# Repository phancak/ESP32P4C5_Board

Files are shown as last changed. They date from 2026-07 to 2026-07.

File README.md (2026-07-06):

# Modular ESP32 Heterogeneous Computing Platform (ESP32-P4 + ESP32-C5)

<div align="center">
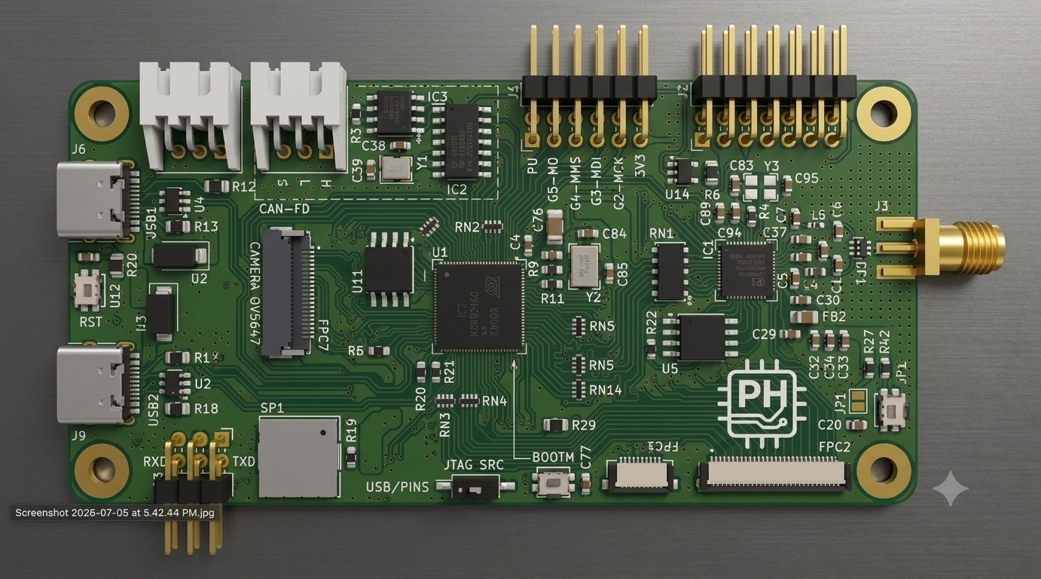
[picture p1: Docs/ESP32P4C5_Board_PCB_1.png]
ESP32P4C5 PCB 3D Render
  
  <br>
  <em>4-layer PCB diagram.</em>
</div>





## 📑 Quick Access
* [**📂 View Project Schematics (PDF)**](./Schematics/ESP32P4C5_Board.pdf)
* [**📂 View PCB Layout (PDF)**](./PCB_Layout/ESP32P4C5_Board.pdf)

## 📌 Project Overview

A production-grade, high-performance development platform engineered to serve as a modular, reusable core for edge computing, high-bandwidth multimedia processing, and synchronized wireless gateways. 

This repository showcases an advanced asynchronous, dual-MCU topology that isolates intensive computational and real-time interface operations from wireless network stack overhead. By decoupling heavy application logic from communication tasks via a high-speed parallel bus interconnect, the architecture guarantees deterministic processing latency and maximum deployment flexibility across diverse industrial and machine vision domains.

---

## 🏗 System Architecture & Design Philosophy

The system architecture purposefully segregates application compute from wireless networking to maximize throughput and guarantee real-time predictability.

<div align="center">
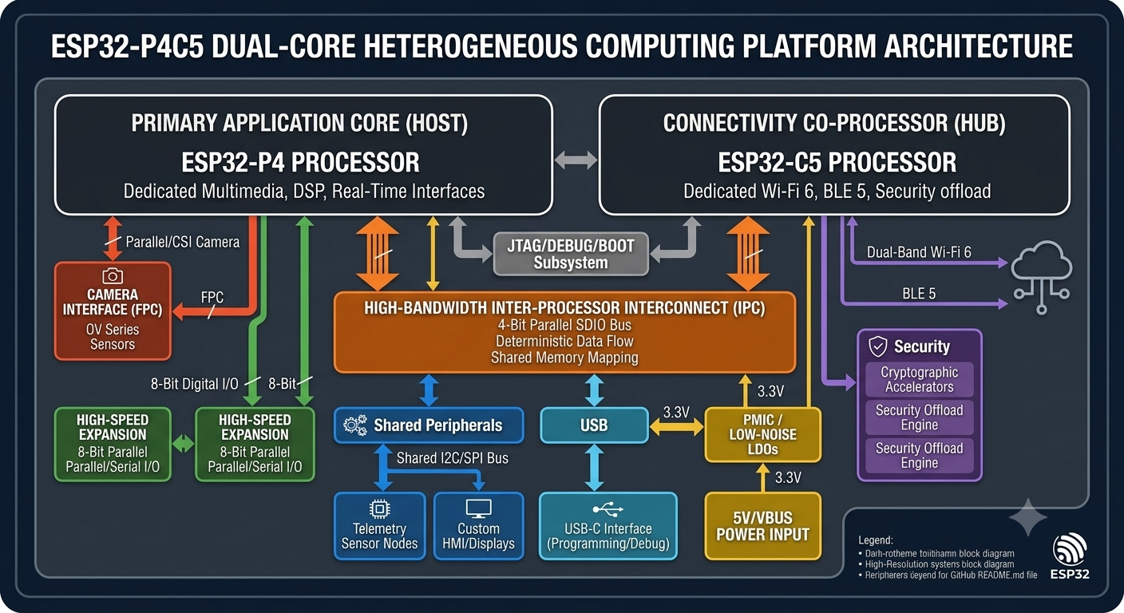
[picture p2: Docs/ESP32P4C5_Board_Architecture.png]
ESP32P4C5 System architecture diagram
  
  <br>
  <em>System architecture diagram.</em>
</div>

### 1. Primary Workstation Core: Espressif ESP32-P4
The **ESP32-P4** acts as the primary host, running application firmwares, digital signal processing (DSP), and complex interface state-machines. It interfaces with high-bandwidth peripherals without experiencing interrupt starvation caused by networking radio activity.
*   **Camera FPC Interface:** A dedicated 0.5mm pitch FPC interface supporting parallel/MIPI CSI camera modules. Designed for minimal trace-length skew to support synchronous high-frame-rate image acquisition and local edge execution.
*   **8-Bit Parallel Subsystem:** Exposes a high-speed, parallel digital bus mapped directly onto low-latency GPIO matrices. Engineered to interface directly with legacy parallel hardware, hardware accelerators, rapid external analog-to-digital converters (ADCs), or high-refresh TFT displays.

### 2. Network Co-Processor Subsystem: Espressif ESP32-C5
The **ESP32-C5** operates as a standalone network engine, handling the entirety of the link layer, cryptographic handshakes, and transport layer protocol stacks.
*   **Dual-Band Wi-Fi 6:** Utilizes native 2.4 GHz and 5 GHz radios, providing network resilience against RF congestion, significantly improving communication reliability in dense industrial environments.
*   **Bluetooth 5 (LE):** Managed independently for local out-of-band provisioning, decentralized mesh topologies, and real-time proximity sensing.

### 3. Inter-Processor Communication (IPC): 4-Bit SDIO Bus
Processor synchronization is achieved over a hardware-managed **4-bit SDIO parallel interface**. Unlike highly bottlenecked SPI or serial UART abstractions, this interconnect introduces wide data paths capable of handling high-rate simultaneous dual-band Wi-Fi data routing concurrently with video capture or high-speed I/O manipulation.

---

## 🔌 Hardware Interface Mapping

To fulfill its requirements as a universally integrable module, the layout strictly organizes peripheral pin assignments to mitigate trace crossover and manage signal integrity across high-speed signal groups.

| Peripheral Subsystem | Physical Interface / Interconnect | Target Engineering Application |
| :--- | :--- | :--- |
| **Edge Vision** | 0.5mm Pitch Parallel FPC | CMOS Image Sensors, Edge AI Machine Vision, Asset Monitoring |
| **Parallel Bus** | Low-Impedance GPIO Headers | Legacy Bus Bridging, High-Speed External Converters, Parallel LCDs |
| **Synchronous Serial**| Hardware SPI Bus Headers | High-Frequency IMUs, External Flash Memory, Low-Level Controllers |
| **Asynchronous Serial**| Dedicated Hardware UART | isolated Console Debugging, GNSS Modems, Cellular Modems |
| **Control Bus** | Fast-Mode Plus (Fm+) I2C | Local Telemetry Sensors, Cryptographic Co-Processors, EEPROMs, HMIs |
| **System I/O & Power** | Dual Independent USB-C | Native USB 2.0 Subsystems, Dedicated Programming/Debugging Bridges |

---

## 🚀 Target Production Domain Implementations

*   **Distributed Edge Machine Vision:** Acquires high-fidelity pixel matrices via the FPC interface, executes localized machine learning inference directly on the application core, and marshals real-time vectors safely out through dual-band Wi-Fi 6.
*   **Industrial Automation & Edge HMI:** Interconnects cleanly with external motor controllers, fieldbuses, or dense sensor pods via the 8-bit parallel, SPI, or I2C busses while handling real-time visualization on local touch displays.
*   **Secure IoT Sensor Hubs:** Operates as a security gateway, pulling data from localized wireless sensor clusters via BLE 5 and uploading encrypted data streams to enterprise cloud nodes across secure 5 GHz channels.

---

## 🛠 System Compilation & Initialization Workflow

### Technical Prerequisites
*   **Espressif ESP-IDF SDK v5.3+** (or later stable branches containing target support for the ESP32-P4 architecture).
*   Standard dual-channel USB-to-UART bridging hardware or explicit configuration via internal USB routing layers.

### Compiling and Deployment
To compile and flash the primary application workspace onto the main ESP32-P4 target engine:

```bash
# Navigate to the core processor application repository
cd firmware/main_p4

# Set compilation targets explicitly to the ESP32-P4 hardware register maps
idf.py set-target esp32p4

# Execute target compilation and code optimization pass
idf.py build

# Flash binary payloads onto the hardware module and open serial communication lines
idf.py -p [YOUR_TARGET_PORT] flash monitor
```

## 📝 License & Open Source Compliance
This architecture and firmware codebase are released under the terms of the open-source MIT License. For complete text and details regarding reuse rights, consult the accompanying LICENSE file.

## 🎓 About the Author
I am a recent **Electrical Engineering graduate from the University of British Columbia (UBC)**. This project represents my ability to transition theoretical academic knowledge into a complex, manufacturable high-speed digital system.

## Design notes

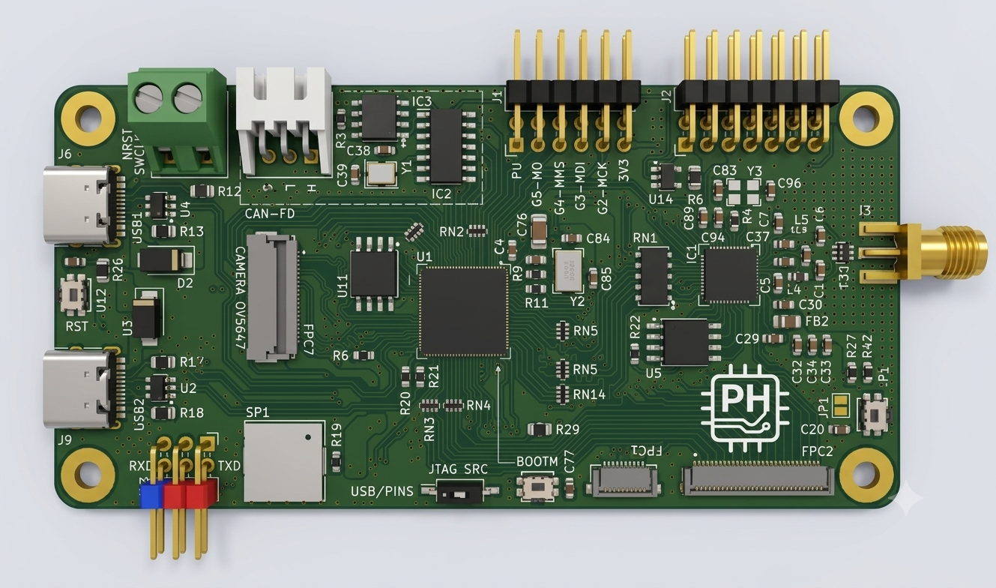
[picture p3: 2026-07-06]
Docs/ESP32P4C5_Board_PCB.png

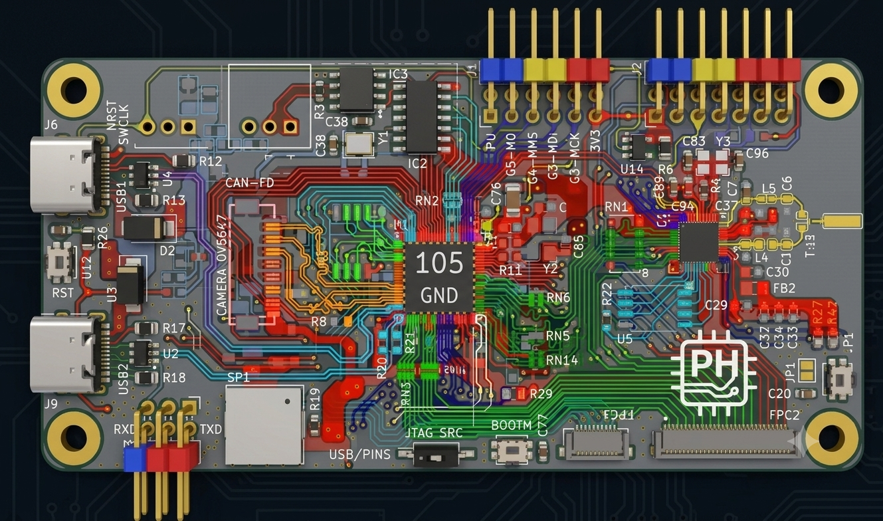
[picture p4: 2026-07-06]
Docs/ESP32P4C5_Board_PCB_Layout.png

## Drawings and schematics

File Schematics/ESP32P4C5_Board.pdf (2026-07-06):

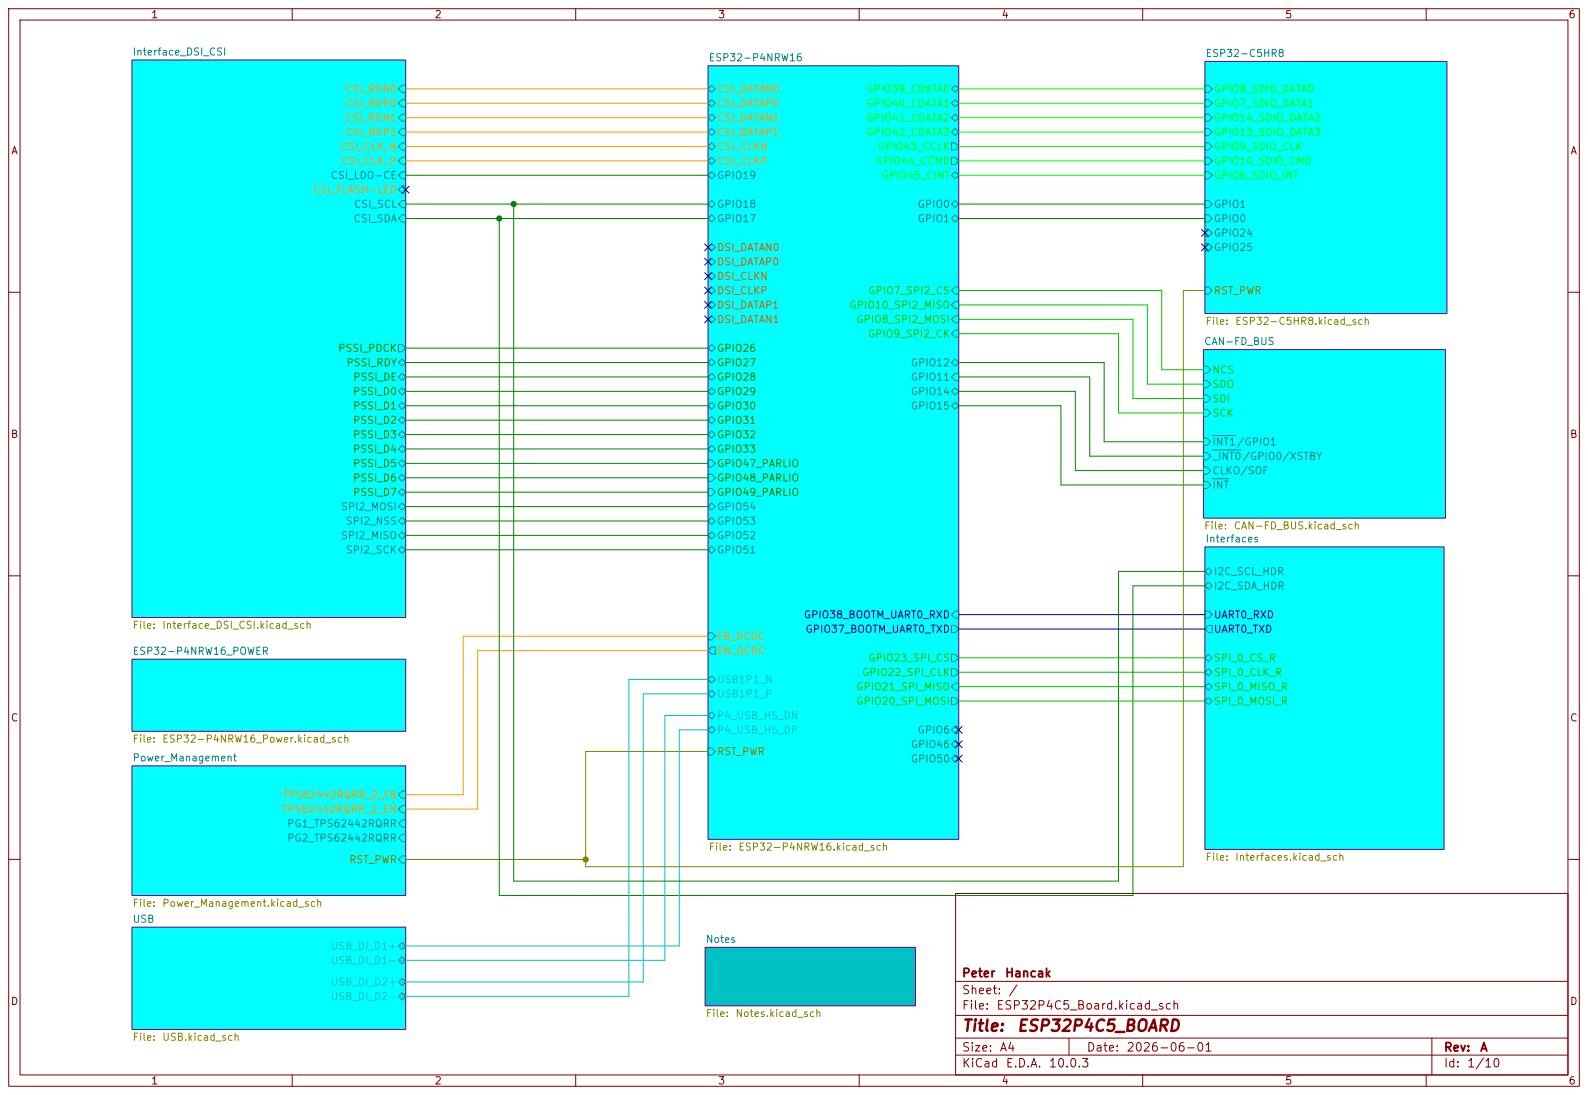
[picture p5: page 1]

CLKO/SOF SCK NCS

File: CAN-FD_BUS.kicad_sch Notes File: Notes.kicad_sch

Size: A4 | Rev: A
KiCad E.D.A. 10.0.3 | Id: 1/10

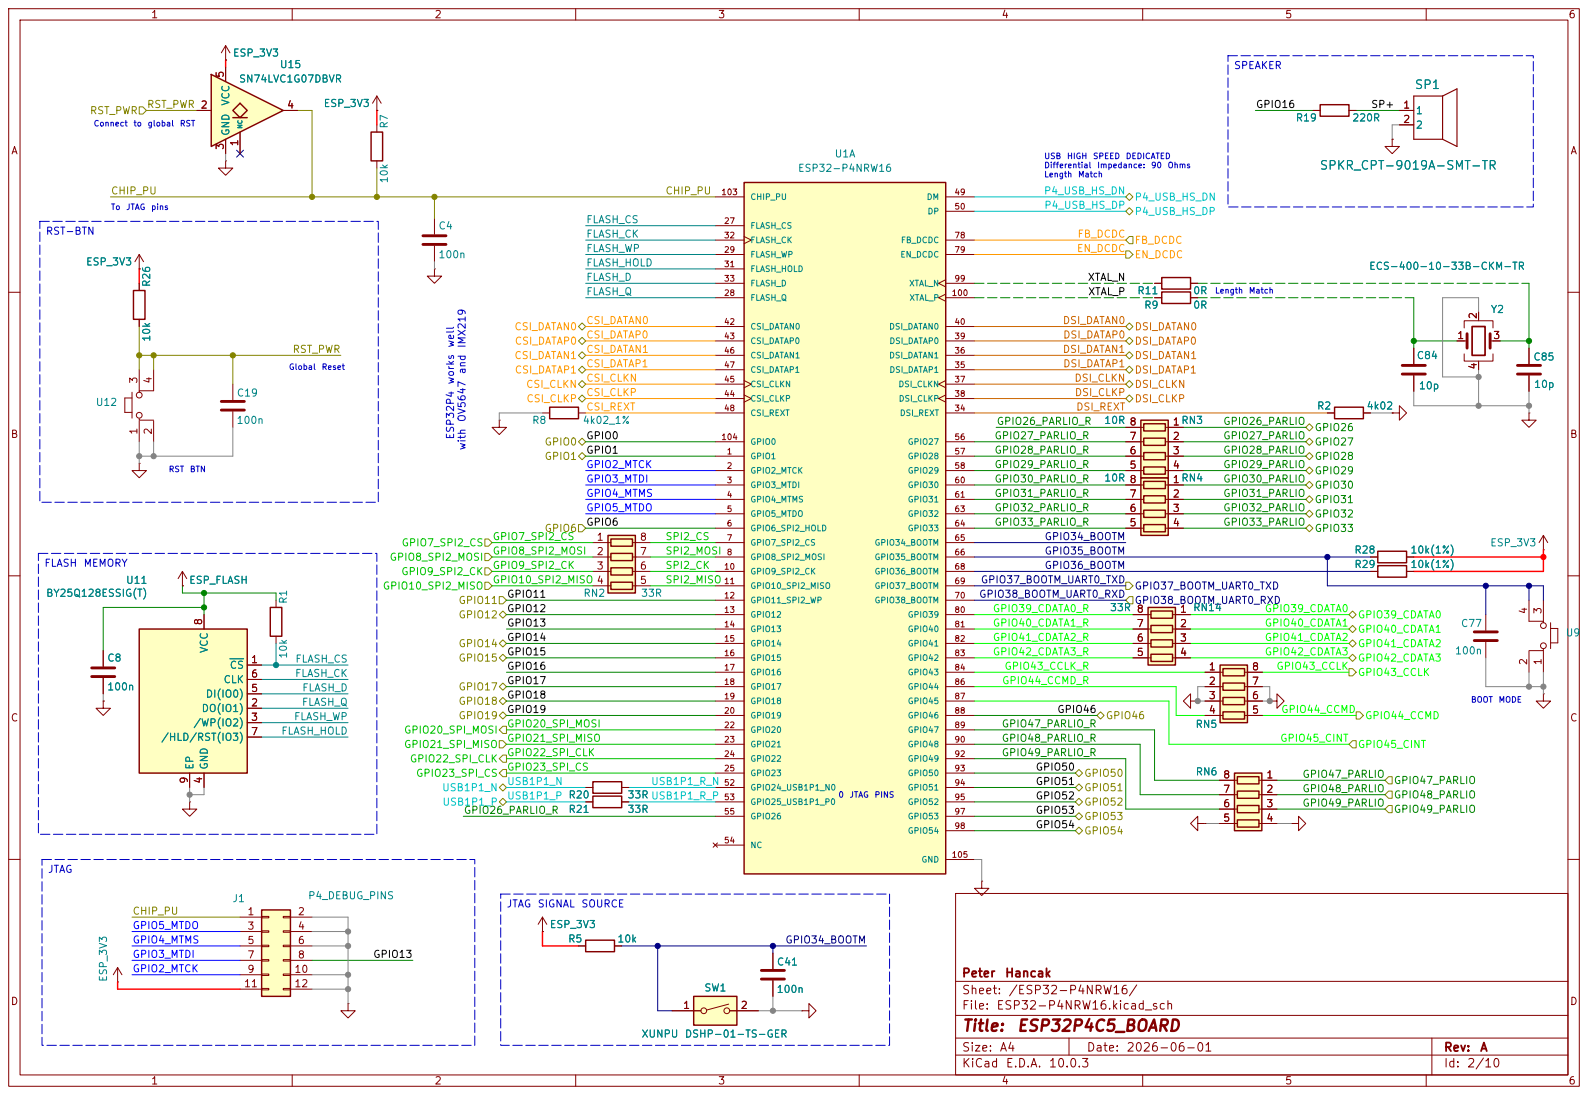
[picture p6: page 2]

Length Match RST BTN

4 DI(IO0) 5 CLK 6 /HLD/RST(IO3) 7 VCC

GPIO40_CDATA1_R 7 7 | 2 2 GPIO40_CDATA1
GPIO41_CDATA2_R 6 6 | GPIO41_CDATA2 3 3
GPIO42_CDATA3_R 5 5 | 4 4 GPIO42_CDATA3

XUNPU DSHP-01-TS-GER

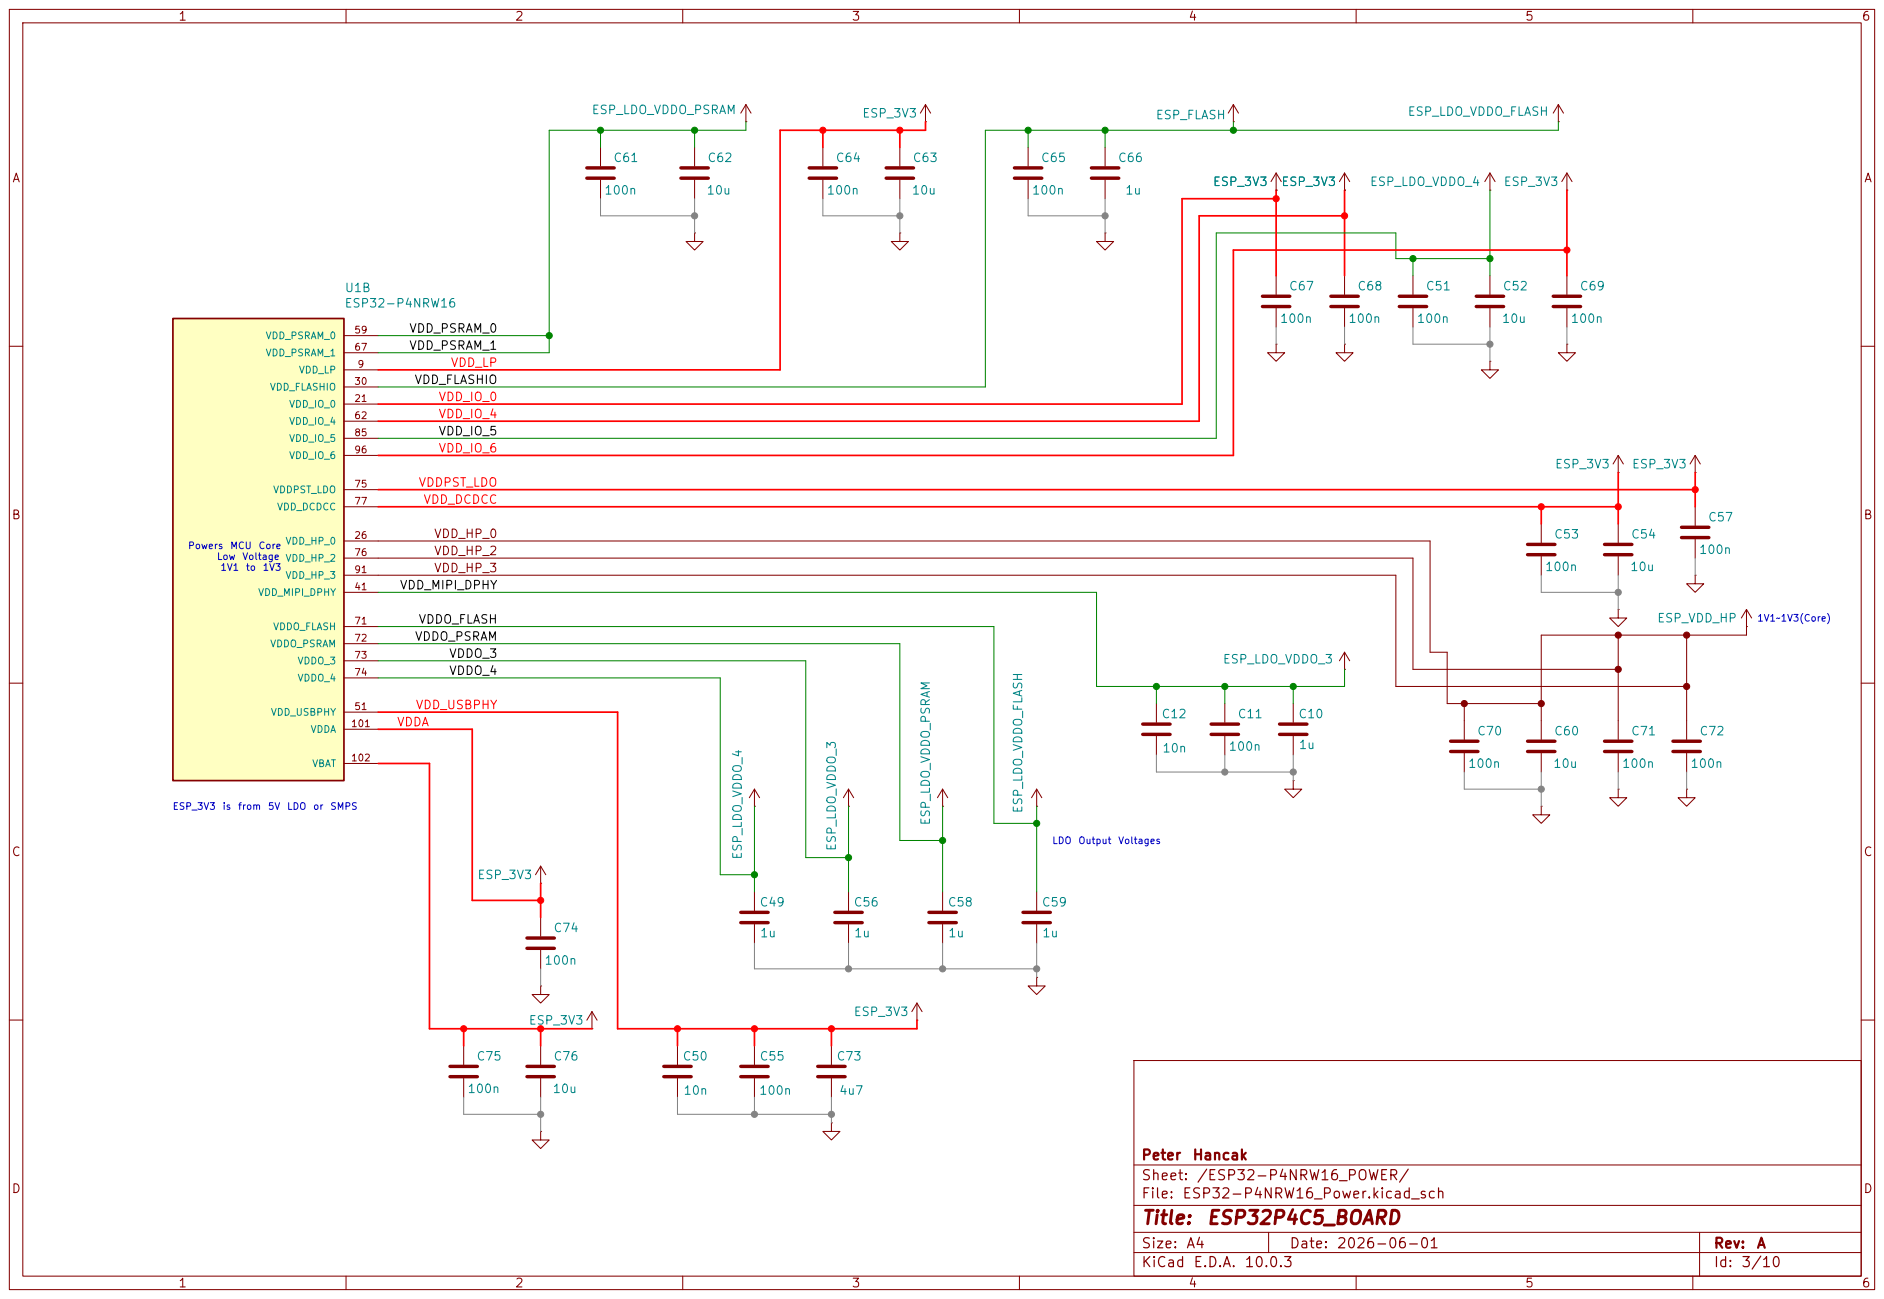
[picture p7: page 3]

VDD_DCDCC

VDD_HP_0

ESP_3V3 is from 5V LDO or SMPS

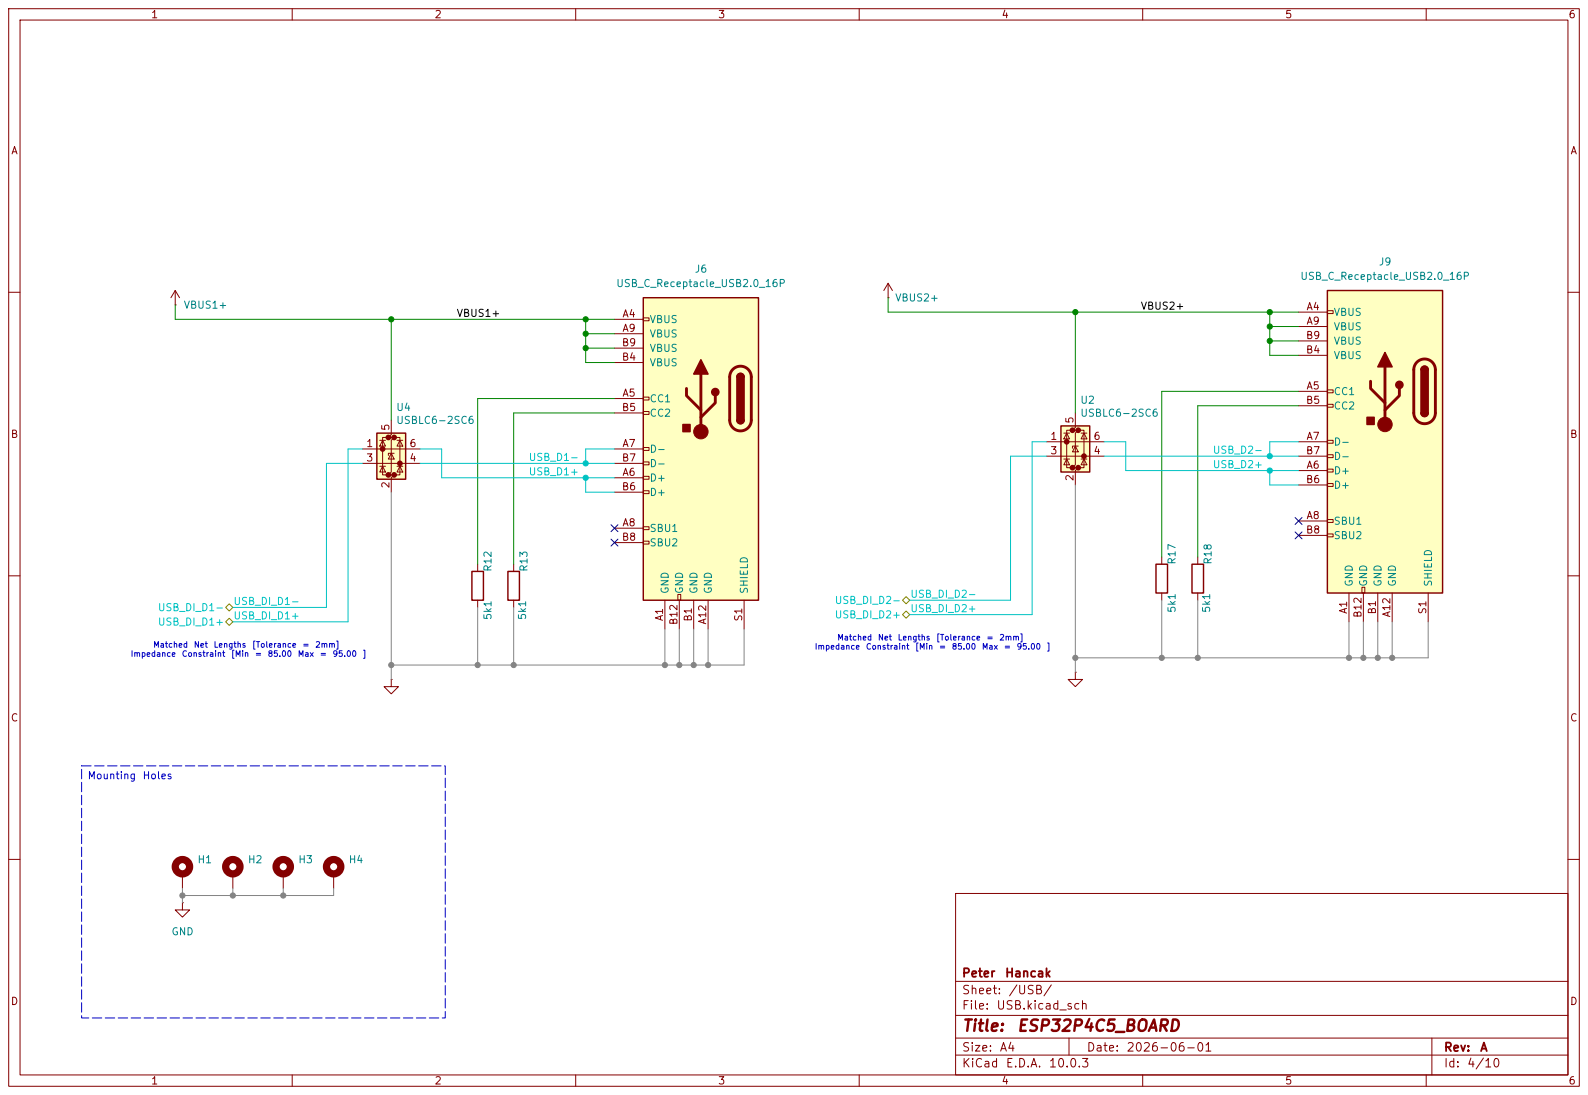
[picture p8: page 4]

VBUS B4 CC2 B5 D+ B6 D- B7

USB_D1+

USB_D2+

Mounting Holes Matched Net Lengths [Tolerance = 2mm]

Impedance Constraint [Min = 85.00 Max = 95.00 ]

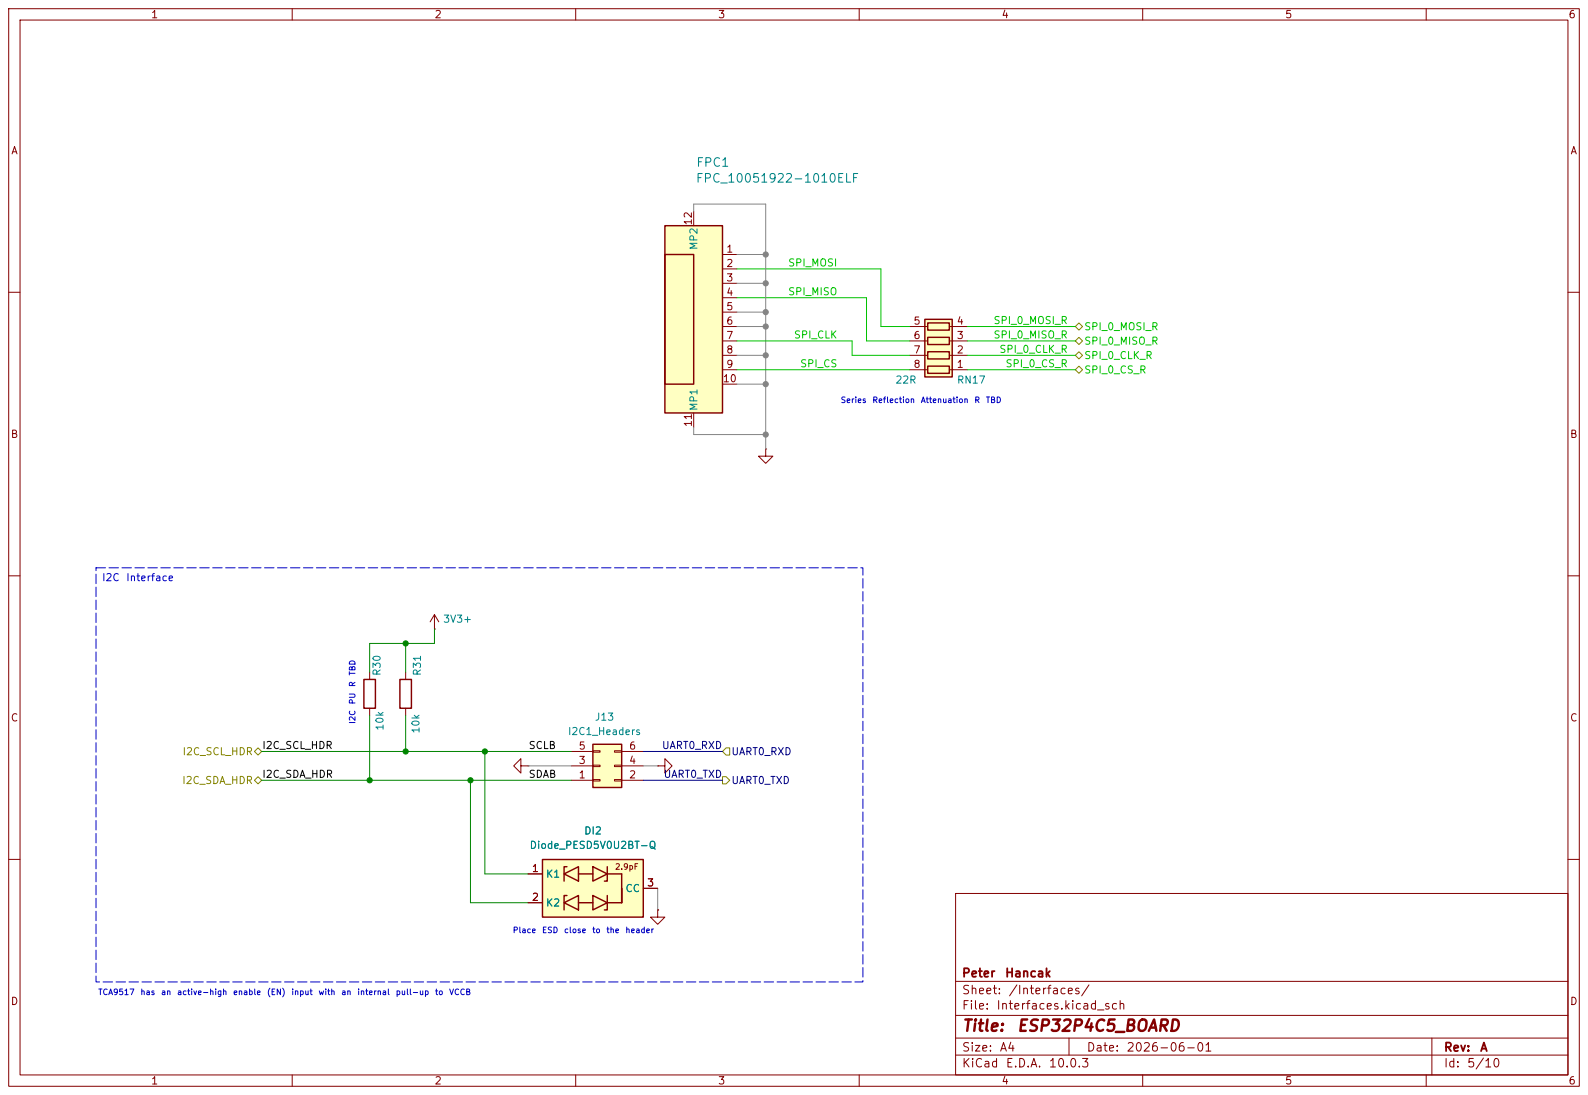
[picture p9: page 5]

8 | SPI_CS | 7

Series Reflection Attenuation R TBD

Place ESD close to the header I2C PU R TBD

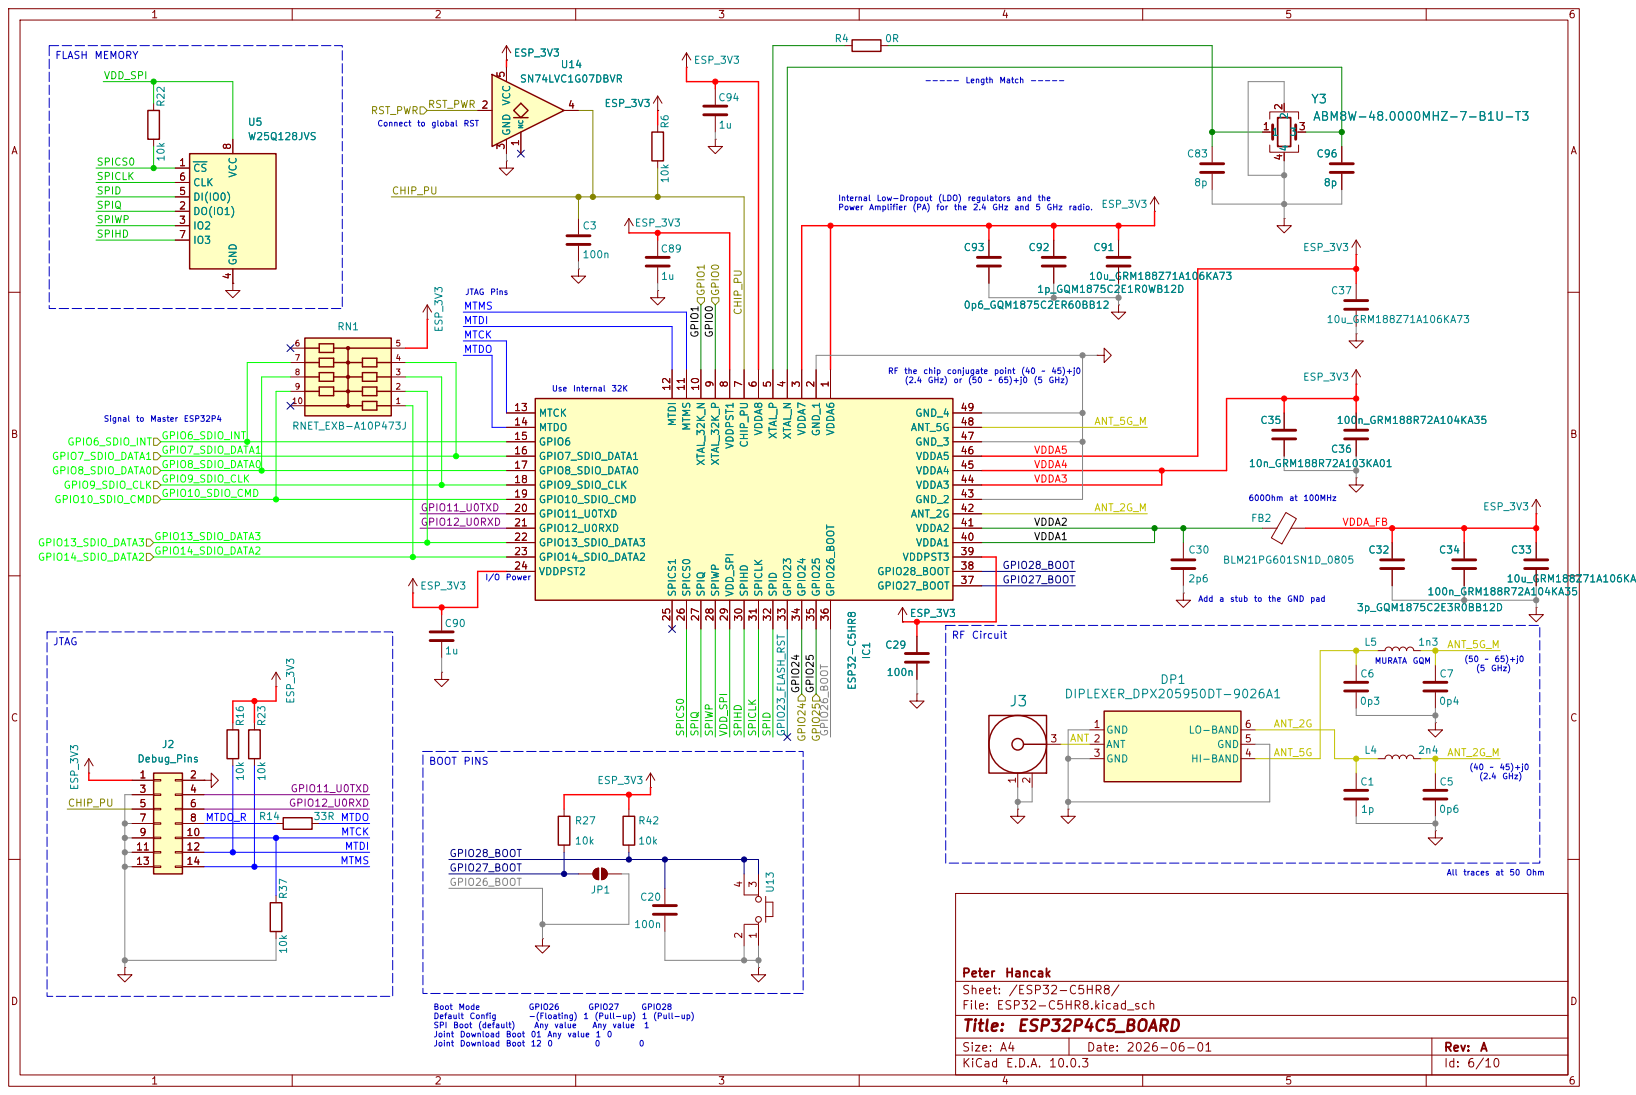
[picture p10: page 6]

RF the chip conjugate point (40 ~ 45)+j0
(2.4 GHz) or (50 ~ 65)+j0 (5 GHz)

9 XTAL_32K_N 10 MTMS 11 MTDI 12 MTCK 13 MTDO 14 GPIO6 15 GPIO7_SDIO_DATA1 16 GPIO8_SDIO_DATA0 17 GPIO9_SDIO_CLK 18 GPIO10_SDIO_CMD 19 GPIO11_U0TXD 20 GPIO12_U0RXD 21 GPIO13_SDIO_DATA3 22 GPIO14_SDIO_DATA2 23

Joint Download Boot 01 Any value 1 0

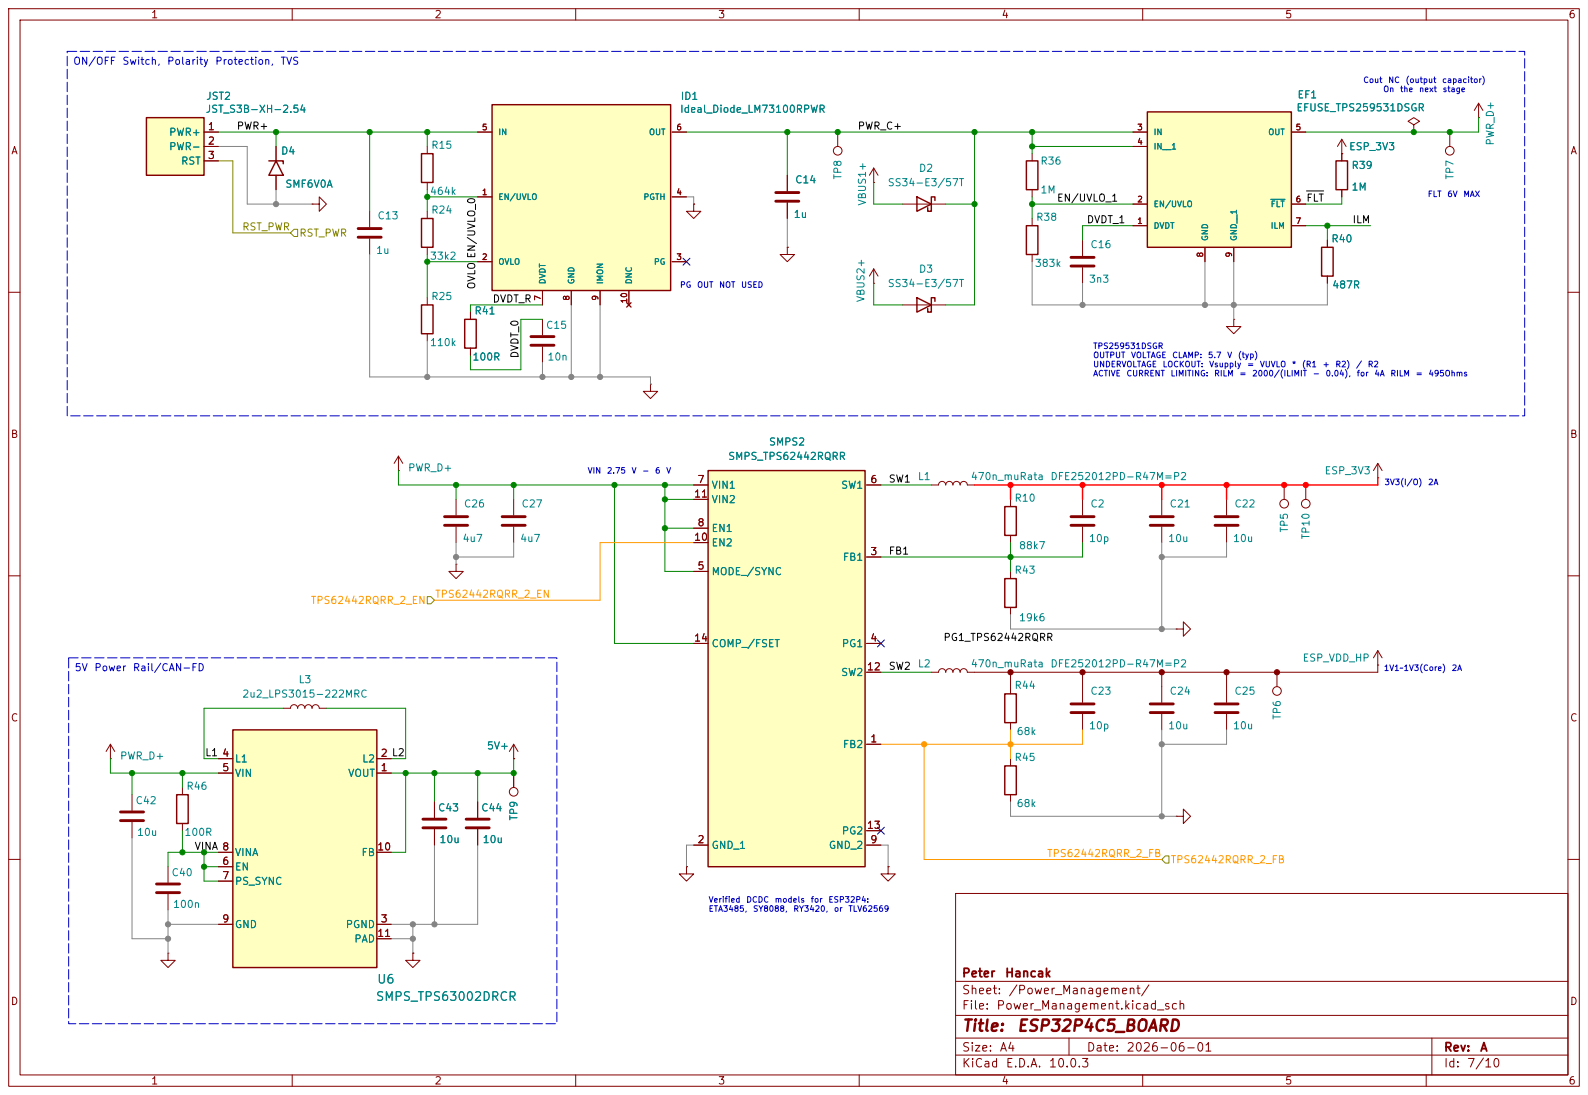
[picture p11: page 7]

ON/OFF Switch, Polarity Protection, TVS
SS34-E3/57T VBUS1+ C14

ACTIVE CURRENT LIMITING: RILM = 2000/(ILIMIT - 0.04), for 4A RILM = 495Ohms Cout NC (output capacitor) On the next stage

TPS259531DSGR OUTPUT VOLTAGE CLAMP: 5.7 V (typ) UNDERVOLTAGE LOCKOUT: Vsupply = VUVLO * (R1 + R2) / R2

Verified DCDC models for ESP32P4: ETA3485, SY8088, RY3420, or TLV62569

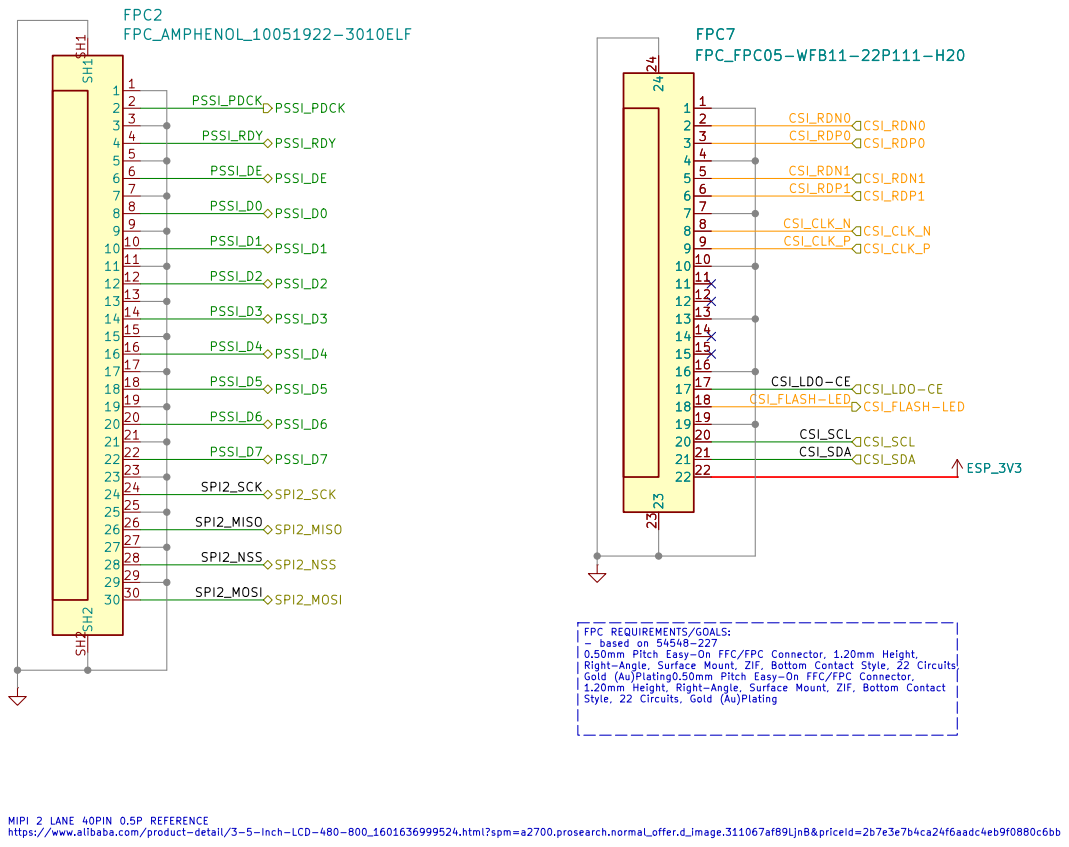
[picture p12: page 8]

https://www.alibaba.com/product-detail/3-5-Inch-LCD-480-800_1601636999524.html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 ESP_3V3 FPC7

FPC REQUIREMENTS/GOALS: - based on 54548-227

0.50mm Pitch Easy-On FFC/FPC Connector, 1.20mm Height, Right-Angle, Surface Mount, ZIF, Bottom Contact Style, 22 Circuits, Gold (Au)Plating0.50mm Pitch Easy-On FFC/FPC Connector, 1.20mm Height, Right-Angle, Surface Mount, ZIF, Bottom Contact Style, 22 Circuits, Gold (Au)Plating MIPI 2 LANE 40PIN 0.5P REFERENCE

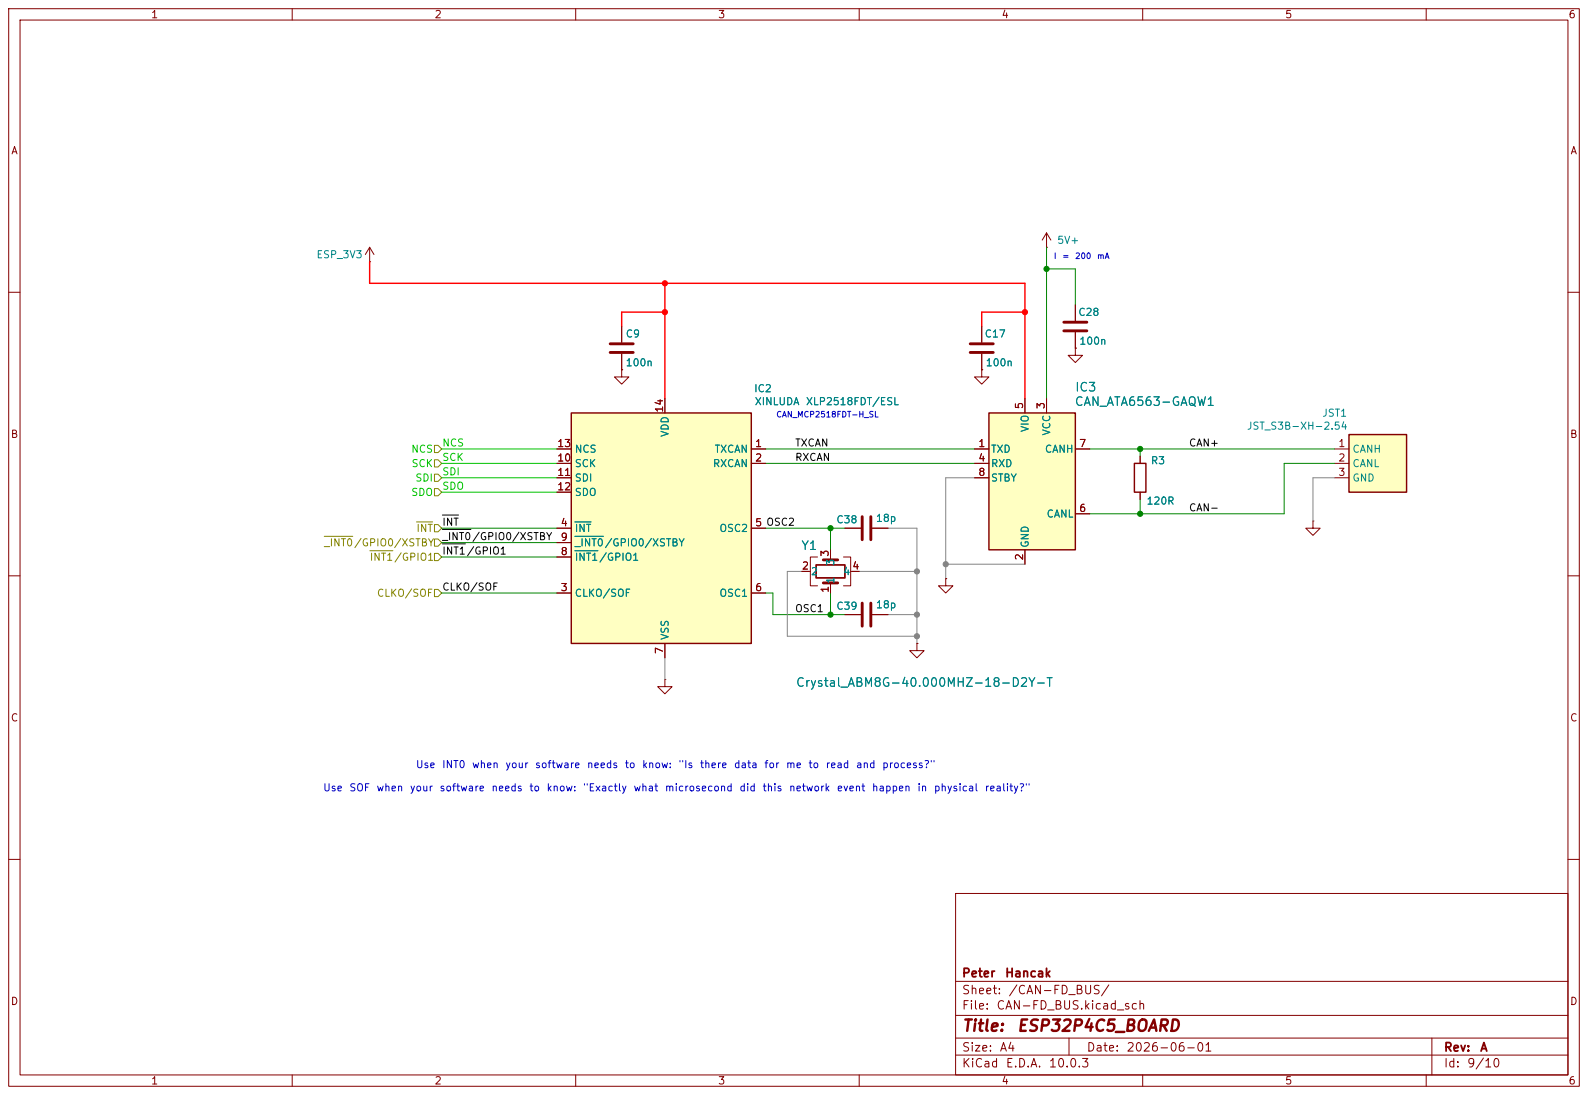
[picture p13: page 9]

CLKO/SOF SCK NCS
SCK NCS

Use INT0 when your software needs to know: "Is there data for me to read and process?" Use SOF when your software needs to know: "Exactly what microsecond did this network event happen in physical reality?" CAN_MCP2518FDT-H_SL

SDI CLKO/SOF SDO

AB

C

D

AB

C

### D Date: 2026-06-01

## Title: ESP32P4C5_BOARD

### File: Notes.kicad_sch

### Sheet: /Notes/

Peter Hancak

PROJECT REQUIREMENTS/GOALS: - Camera OV5647 to capture real-time vide (or smiliar) - Provide WIFI link (to transmit the real-time video) - Control motor through CAN-FD interface - High Speed 8-bit pparallel connection to expansion PCBs - High Speed USB connector - I2C, UART, SPI (through FPC) interfaces SECONDARY GOALS: - Function as a simple server - Motor control through PWM pins - LCD with touch screen (MIPI 2LANE)

POWER MANAGEMENT NOTES: - The input power goes through three stages 1. a) External Power: LM73100RPWR, 2.7 - 23 V, 5.5 A Integrated Ideal Diode with Input Reverse Polarity and Overvoltage Protection

b) USB POWER: SS34-E3/57T Diode 2. TPS259531DSGR 2.7V to 18V, 4-A, 34-mΩ eFuse With Fast Overvoltage Protection 3. TPS62442RQRR, 2.75-V to 6-V, Dual-Channel Step-Down Converter with Adjustable

Frequency - Stage Description: 1. The power is sourced from the imediatelly connected power source without relying on

jumpers to manual selection. The diodes prevent current from flowing back to a source in case of multiple ppower sources being conected. The ideal diode was used for thhe external power source to limit power loss inherent in a

regular diode as the eternal power source will at times be a battery. The ideal diode includes ppolarity protection (not required on the USB sources) 2. The eFuse provides overvoltage protection, undervoltage lockout, Short Circuit Protection, and limits inrussh current. 3. SMPS that outputs two power rails. The first is dedicated and controlled by the ESP32P4

core. The second is general 3.3V power rail used by all other components. ESP32P4 Power Domains - THE VDD_HP pins: 600mA to 1A Current, Required Width: 0.3 mm (1A)

Ideal Diode LM73100RPWR Parameter Notes: - Maximum System Peak Current (IOUT): 2.5 A (to cleanly capture joint ESP32 radio bursts, camera operations, and converter losses). - I IMON is not used (connected to GND), no monitoring pins available on the MCU - Calculate the Value for RIMON = VADC_MAX/IIMON = 3.3 V/452.5 μA ≈ 7.29 kΩ IMON
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

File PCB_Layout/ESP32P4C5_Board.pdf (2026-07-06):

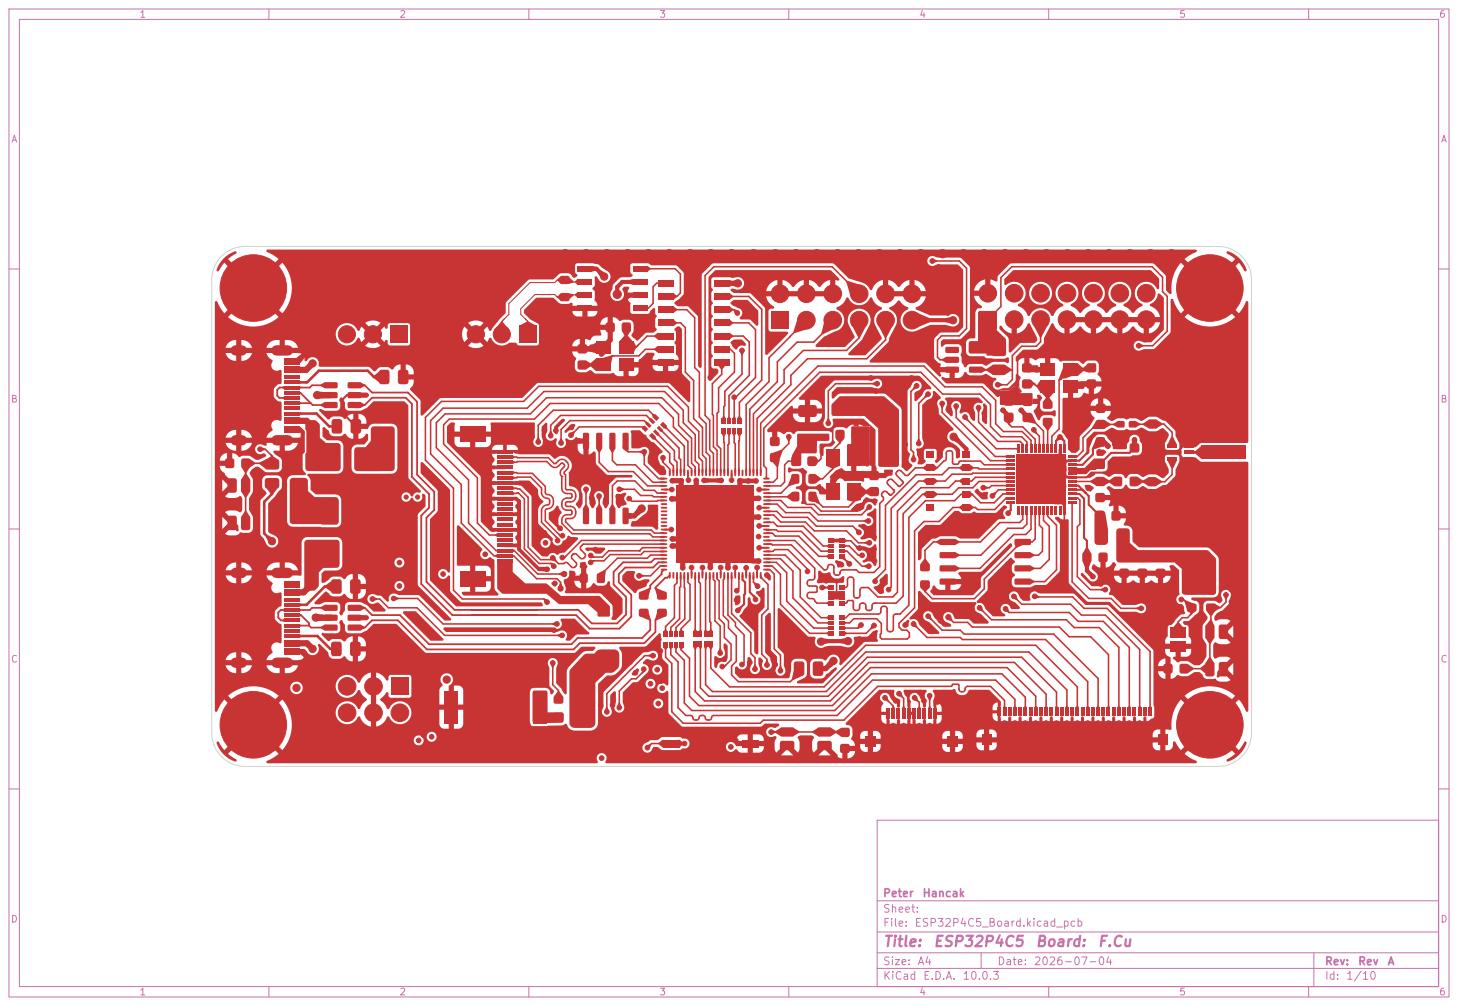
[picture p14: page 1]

Size: A4 | Rev: Rev A
KiCad E.D.A. 10.0.3 | Id: 1/10

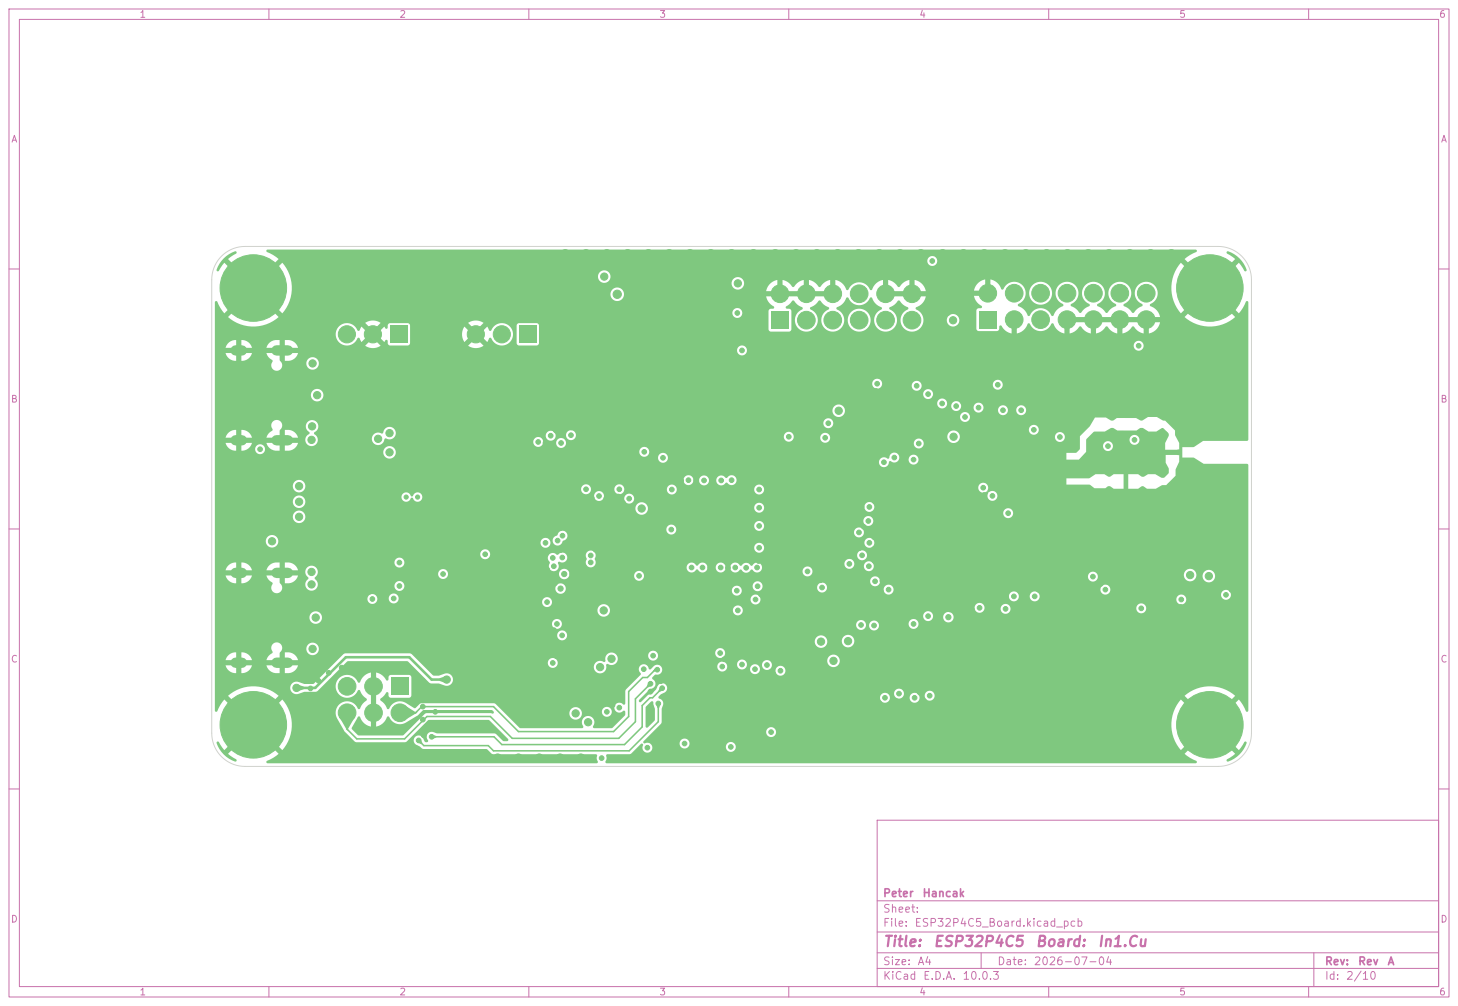
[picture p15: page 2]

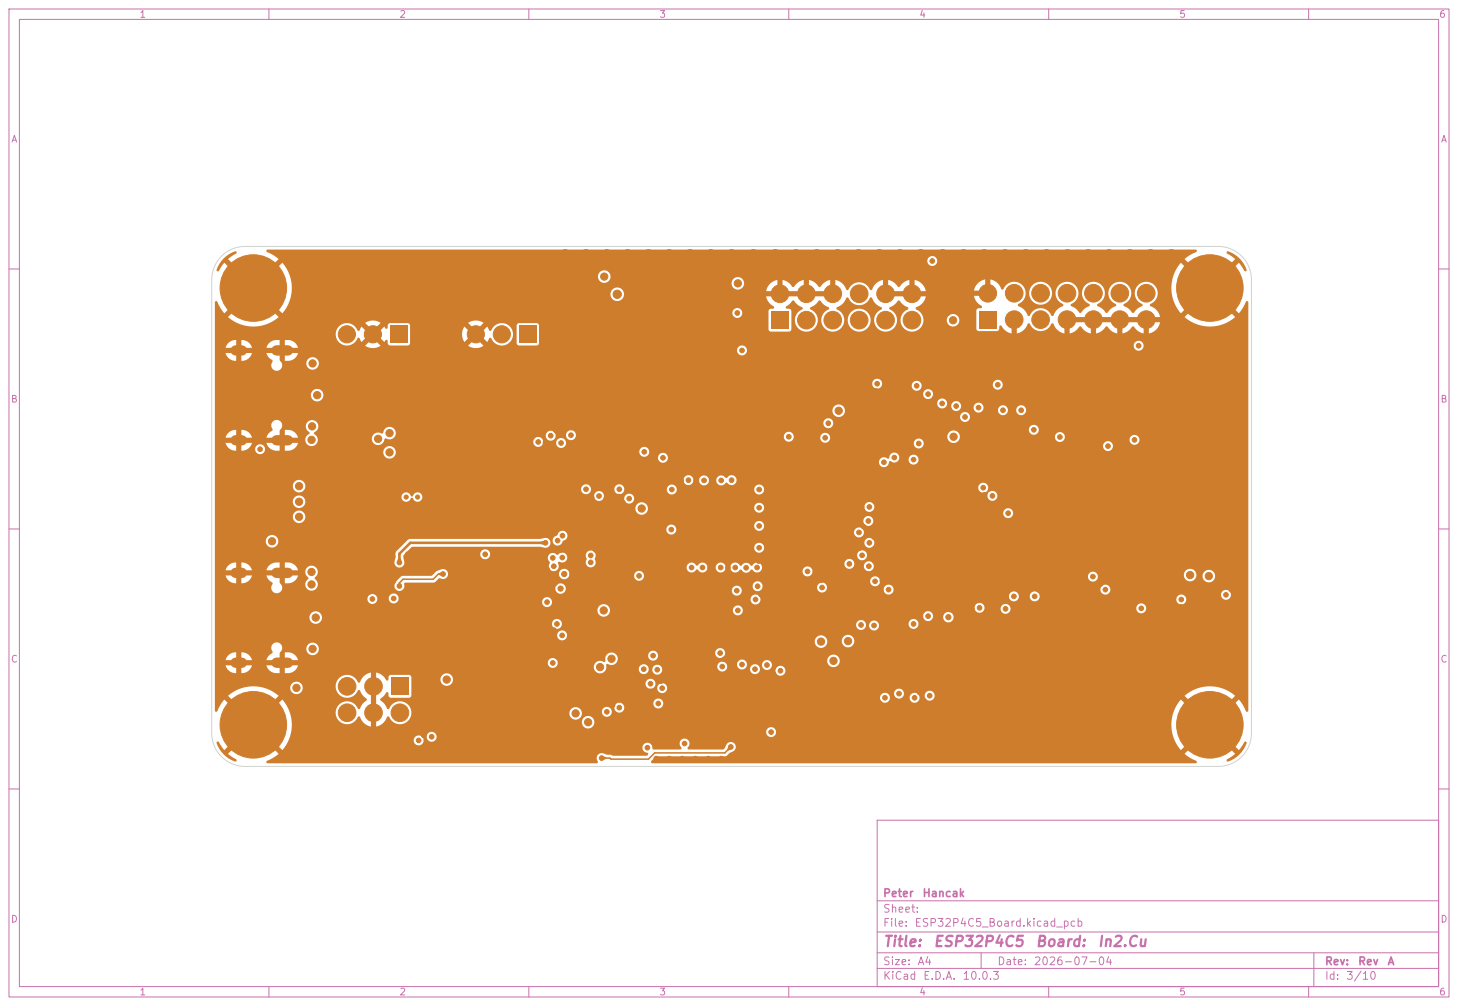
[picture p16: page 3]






CL:1 OP:0, Mode, Boot Download Joint - JP1



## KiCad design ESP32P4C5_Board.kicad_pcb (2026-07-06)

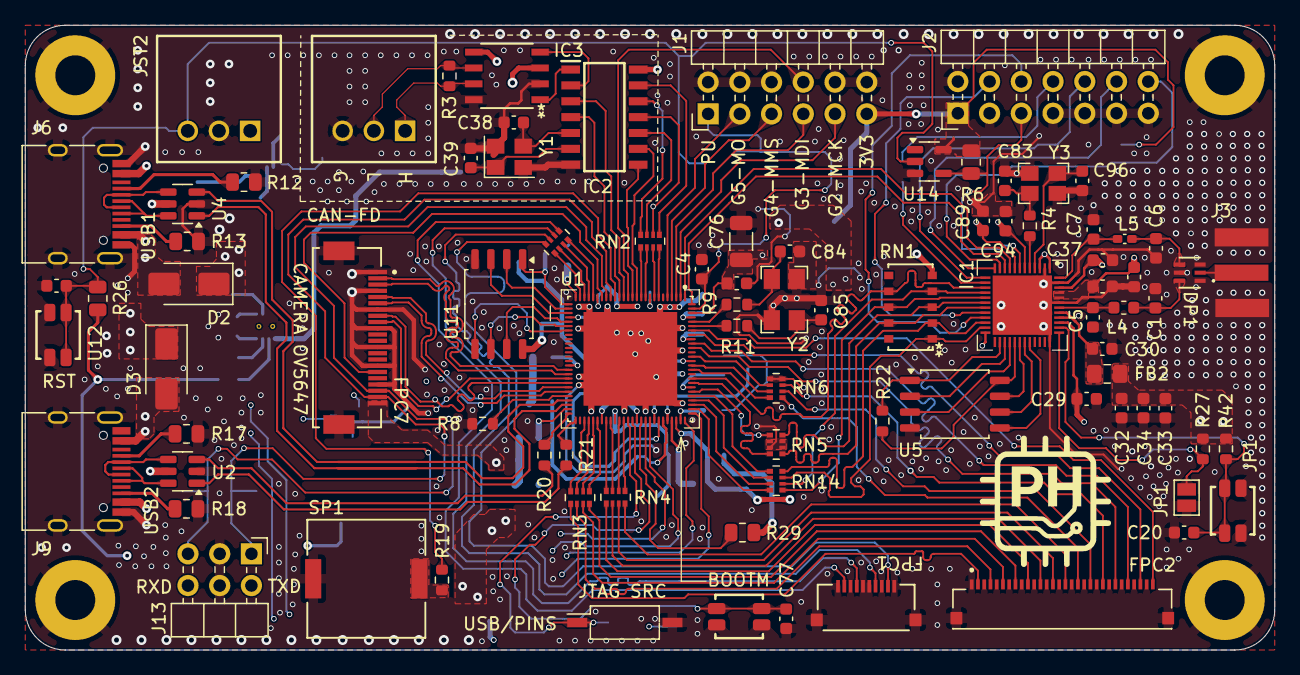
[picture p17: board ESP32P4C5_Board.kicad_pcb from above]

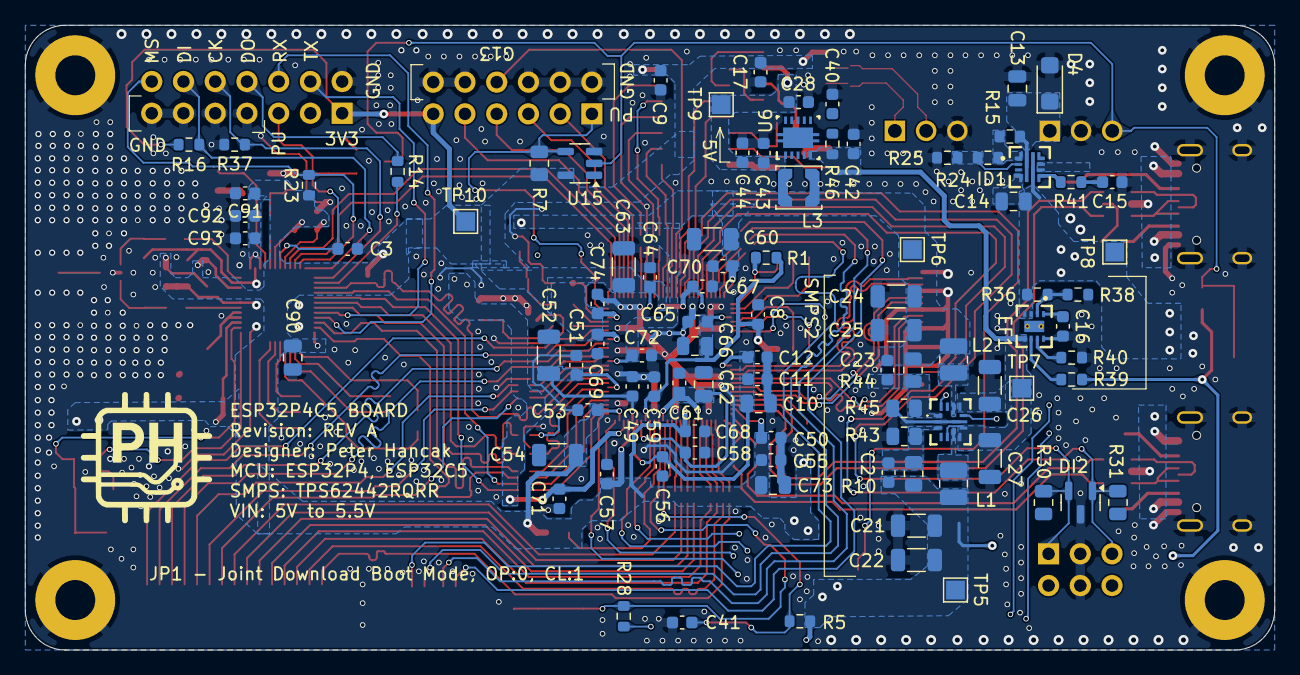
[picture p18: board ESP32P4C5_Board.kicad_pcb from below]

Board: 4 copper layers, 100.0 x 50.0 mm, 185 parts (94 on the bottom side), 171 nets.

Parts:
C1: 1p; C_0603_1608Metric
C2, C23, C84, C85: 10p; C_0603_1608Metric
C3, C4, C8, C9, C11, C17, C19, C20, C28, C29, C40, C41, C51, C53, C55, C57, C61, C64, C65, C67, C68, C69, C70, C71, C72, C74, C75, C77: 100n; C_0603_1608Metric
C5: 0p6; C_0603_1608Metric
C6: 0p3; C_0603_1608Metric
C7: 0p4; C_0603_1608Metric
C10, C13, C14, C66, C90: 1u; C_0805_2012Metric
C12, C15, C50: 10n; C_0603_1608Metric
C16: 3n3; C_0603_1608Metric
C21, C22, C24, C25, C52, C54, C60, C63, C76: 10u; C_1206_3216Metric
C26, C27: 4u7; C_1206_3216Metric
C30: 2p6; C_0603_1608Metric
C32: 3p_GQM1875C2E3R0BB12D; C_0603_1608Metric
C33, C37, C91: 10u_GRM188Z71A106KA73; C_0603_1608Metric
C34, C36: 100n_GRM188R72A104KA35; C_0603_1608Metric
C35: 10n_GRM188R72A103KA01; C_0603_1608Metric
C38, C39: 18p; C_0603_1608Metric
C42, C43, C44: 10u; C_0603_1608Metric
C49, C56, C58, C59, C89, C94: 1u; C_0603_1608Metric
C62: 10u; C_0805_2012Metric
C73: 4u7; C_0805_2012Metric
C83, C96: 8p; C_0603_1608Metric
C92: 1p_GQM1875C2E1R0WB12D; C_0603_1608Metric
C93: 0p6_GQM1875C2ER60BB12; C_0603_1608Metric
D2, D3: SS34-E3/57T; D_SMA
D4: SMF6V0A; D_SMF
DI2: Diode_PESD5V0U2BT-Q; SOT-23
DP1: DIPLEXER_DPX205950DT-9026A1
EF1: EFUSE_TPS259531DSGR
FB2: BLM21PG601SN1D_0805; C_0805_2012Metric_Pad1.18x1.45mm_HandSolder
FPC1: FPC_10051922-1010ELF; FPC_10051922_1010
FPC2: FPC_AMPHENOL_10051922-3010ELF
FPC7: FPC_FPC05-WFB11-22P111-H20
H1, H2, H3, H4: MountingHole_Pad; MountingHole_3.2mm_M3_Pad
IC1: ESP32-C5HR8; QFN40P600X600X90-49N-D
IC2: XINLUDA XLP2518FDT/ESL; CAN_MCP2518FDT-H_SL
IC3: CAN_ATA6563-GAQW1; CAN_ATA6563_GAQW1
ID1: Ideal_Diode_LM73100RPWR
J1: P4_DEBUG_PINS; PinHeader_2x06_P2.54mm_Horizontal
J2: Debug_Pins; PinHeader_2x07_P2.54mm_Horizontal
J3: SMA PCB END LAUNCH JACK ROUND PO; SMA Clip Mount Adapter (top)
J6, J9: USB_C_Receptacle_USB2.0_16P; USB_C_Receptacle_HRO_TYPE-C-31-M-12
J13: I2C1_Headers; PinHeader_2x03_P2.54mm_Horizontal_Court
JP1: SolderJumper_2_Open; SolderJumper-2_P1.3mm_Open_Pad1.0x1.5mm
JST1, JST2: JST_S3B-XH-2.54; JST_S3B-XH-SHDRRA3W64P0X250_1X3_990X1150X610P
L1, L2: 470n_muRata DFE252012PD-R47M=P2; L_1008_2520Metric
L3: 2u2_LPS3015-222MRC; L_Coilcraft_LPS3010
L4: 2n4; L_0603_1608Metric
L5: 1n3; L_0402_1005Metric_Pad0.77x0.64mm_HandSolder
R1, R5, R16, R22, R23, R27, R37, R42: 10k; R_0603_1608Metric
R3: 120R; R_0603_1608Metric
R4, R9, R11: 0R; R_0603_1608Metric
R6, R7, R26, R30, R31: 10k; R_0805_2012Metric
R8: 4k02_1%; R_0603_1608Metric
R10: 88k7; R_0805_2012Metric
R12, R13, R17, R18: 5k1; R_0805_2012Metric
R14, R20, R21: 33R; R_0603_1608Metric
R15: 464k; R_0603_1608Metric
R19: 220R; R_0603_1608Metric
R24: 33k2; R_0603_1608Metric
R25: 110k; R_0603_1608Metric
R28: 10k(1%); R_0603_1608Metric
R29: 10k(1%); R_0805_2012Metric_1
R36, R39: 1M; R_0603_1608Metric
R38: 383k; R_0603_1608Metric
R40: 487R; R_0603_1608Metric
R41, R46: 100R; R_0603_1608Metric
R43: 19k6; R_0805_2012Metric
R44, R45: 68k; R_0805_2012Metric
RN1: RNET_EXB-A10P473J
RN2, RN5, RN6, RN14: 33R; R_Array_Convex_4x0402
RN3, RN4: 10R; R_Array_Convex_4x0402
RN17: 22R; R_Array_Convex_4x0402
SMPS2: SMPS_TPS62442RQRR
SP1: SPKR_CPT-9019A-SMT-TR; SPKR_CPT-9019A
SW1: XUNPU DSHP-01-TS-GER; SW_DIP_SPSTx01_Slide_Copal_CHS-01B_W7.62mm_P1.27mm
TP5, TP6, TP7, TP8, TP9, TP10: TestPoint; TestPoint_Pad_1.5x1.5mm
U1: ESP32-P4NRW16
U2, U4: USBLC6-2SC6; SOT-23-6
U5: W25Q128JVS; SOIC-8_5.23x5.23mm_P1.27mm
U6: SMPS_TPS63002DRCR; SMPS_TPS63002DRCR_10-VSON
U9, U12, U13: Button_SKSCLCE010
U11: BY25Q128ESSIG(T); SOP-8_5.28x5.23mm_P1.27mm
U14, U15: SN74LVC1G07DBVR; SOT-23-5
Y1: Crystal_ABM8G-40.000MHZ-18-D2Y-T; Crystal_SMD_Abracon_ABM8G-4Pin_3.2x2.5mm
Y2: ECS-400-10-33B-CKM-TR; Crystal_ECS-400-10-30B-CKM-TR
Y3: ABM8W-48.0000MHZ-7-B1U-T3; Crystal_SMD_Abracon_ABM8AIG-4Pin_3.2x2.5mm

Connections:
3V3+: R30.1, R31.1
5V+: C28.1, C43.2, C44.2, IC3.3 (VCC), TP9.1 (1_1), U6.1 (VOUT), U6.10 (FB)
/CAN-FD_BUS/CAN+: IC3.7 (CANH), JST1.1 (CANH), R3.1
/CAN-FD_BUS/CAN-: IC3.6 (CANL), JST1.2 (CANL), R3.2
/CAN-FD_BUS/CLKO/SOF: IC2.3 (CLKO/SOF), U1.15 (GPIO14)
/CAN-FD_BUS/NCS: IC2.13 (NCS), RN2.1 (R1.1)
/CAN-FD_BUS/OSC1: C39.1, IC2.6 (OSC1), Y1.1
/CAN-FD_BUS/OSC2: C38.1, IC2.5 (OSC2), Y1.3
/CAN-FD_BUS/RXCAN: IC2.2 (RXCAN), IC3.4 (RXD)
/CAN-FD_BUS/SCK: IC2.10 (SCK), RN2.3 (R3.1)
/CAN-FD_BUS/SDI: IC2.11 (SDI), RN2.2 (R2.1)
/CAN-FD_BUS/SDO: IC2.12 (SDO), RN2.4 (R4.1)
/CAN-FD_BUS/TXCAN: IC2.1 (TXCAN), IC3.1 (TXD)
/CAN-FD_BUS/~INT1/GPIO1: IC2.8 (~INT1/GPIO1), U1.13 (GPIO12)
/CAN-FD_BUS/~INT: IC2.4 (~INT), U1.16 (GPIO15)
/CAN-FD_BUS/~_INT0/GPIO0/XSTBY: IC2.9 (~_INT0/GPIO0/XSTBY), U1.12 (GPIO11_SPI2_WP)
/ESP32-C5HR8/ANT: DP1.2 (ANT), J3.3 (Signal)
/ESP32-C5HR8/ANT_2G: C1.1, DP1.6 (LO-BAND), L4.1
/ESP32-C5HR8/ANT_2G_M: C5.1, IC1.42 (ANT_2G), L4.2
/ESP32-C5HR8/ANT_5G: C6.1, DP1.4 (HI-BAND), L5.1
/ESP32-C5HR8/ANT_5G_M: C7.1, IC1.48 (ANT_5G), L5.2
/ESP32-C5HR8/CHIP_PU: C3.1, IC1.7 (CHIP_PU), J2.5, R6.2, U14.4
/ESP32-C5HR8/GPIO0: IC1.9 (XTAL_32K_P), U1.1 (GPIO1)
/ESP32-C5HR8/GPIO1: IC1.10 (XTAL_32K_N), U1.104 (GPIO0)
/ESP32-C5HR8/GPIO6_SDIO_INT: IC1.15 (GPIO6), RN1.7, U1.87 (GPIO45)
/ESP32-C5HR8/GPIO7_SDIO_DATA1: IC1.16 (GPIO7_SDIO_DATA1), RN1.4, RN14.2 (R2.1)
/ESP32-C5HR8/GPIO8_SDIO_DATA0: IC1.17 (GPIO8_SDIO_DATA0), RN1.8, RN14.1 (R1.1)
/ESP32-C5HR8/GPIO9_SDIO_CLK: IC1.18 (GPIO9_SDIO_CLK), RN1.3, RN5.8 (R1.2)
/ESP32-C5HR8/GPIO10_SDIO_CMD: IC1.19 (GPIO10_SDIO_CMD), RN1.9, RN5.5 (R4.2)
/ESP32-C5HR8/GPIO11_U0TXD: IC1.20 (GPIO11_U0TXD), J2.4
/ESP32-C5HR8/GPIO12_U0RXD: IC1.21 (GPIO12_U0RXD), J2.6
/ESP32-C5HR8/GPIO13_SDIO_DATA3: IC1.22 (GPIO13_SDIO_DATA3), RN1.2, RN14.4 (R4.1)
/ESP32-C5HR8/GPIO14_SDIO_DATA2: IC1.23 (GPIO14_SDIO_DATA2), RN1.1, RN14.3 (R3.1)
/ESP32-C5HR8/GPIO27_BOOT: IC1.37 (GPIO27_BOOT), JP1.2 (B), R27.2
/ESP32-C5HR8/GPIO28_BOOT: C20.2, IC1.38 (GPIO28_BOOT), R42.2, U13.3, U13.4
/ESP32-C5HR8/MTCK: IC1.13 (MTCK), J2.10, R37.1
/ESP32-C5HR8/MTDI: IC1.12 (MTDI), J2.12, R16.2
/ESP32-C5HR8/MTDO: IC1.14 (MTDO), R14.2
/ESP32-C5HR8/MTDO_R: J2.8, R14.1
/ESP32-C5HR8/MTMS: IC1.11 (MTMS), J2.14, R23.2
/ESP32-C5HR8/RST_PWR: C19.2, JST2.3 (RST), R26.2, U12.3, U12.4, U14.2, U15.2
/ESP32-C5HR8/SPICLK: IC1.31 (SPICLK), U5.6 (CLK)
/ESP32-C5HR8/SPICS0: IC1.26 (SPICS0), R22.2, U5.1 (~CS)
/ESP32-C5HR8/SPID: IC1.32 (SPID), U5.5 (DI(IO0))
/ESP32-C5HR8/SPIHD: IC1.30 (SPIHD), U5.7 (IO3)
/ESP32-C5HR8/SPIQ: IC1.27 (SPIQ), U5.2 (DO(IO1))
/ESP32-C5HR8/SPIWP: IC1.28 (SPIWP), U5.3 (IO2)
/ESP32-C5HR8/VDDA1: C30.1, FB2.1, IC1.40 (VDDA1), IC1.41 (VDDA2)
/ESP32-C5HR8/VDD_SPI: IC1.29 (VDD_SPI), R22.1, U5.8 (VCC)
/ESP32-P4NRW16/CHIP_PU: C4.1, J1.1, R7.2, U1.103 (CHIP_PU), U15.4
/ESP32-P4NRW16/CSI_CLKN: FPC7.8, U1.45 (CSI_CLKN)
/ESP32-P4NRW16/CSI_CLKP: FPC7.9, U1.44 (CSI_CLKP)
/ESP32-P4NRW16/CSI_DATAN0: FPC7.2, U1.42 (CSI_DATAN0)
/ESP32-P4NRW16/CSI_DATAN1: FPC7.5, U1.46 (CSI_DATAN1)
/ESP32-P4NRW16/CSI_DATAP0: FPC7.3, U1.43 (CSI_DATAP0)
/ESP32-P4NRW16/CSI_DATAP1: FPC7.6, U1.47 (CSI_DATAP1)
/ESP32-P4NRW16/CSI_REXT: R8.2, U1.48 (CSI_REXT)
/ESP32-P4NRW16/EN_DCDC: SMPS2.10 (EN2), U1.79 (EN_DCDC)
/ESP32-P4NRW16/FB_DCDC: C23.1, R44.2, R45.1, SMPS2.1 (FB2), U1.78 (FB_DCDC)
/ESP32-P4NRW16/FLASH_CK: U1.32 (FLASH_CK), U11.6 (CLK)
/ESP32-P4NRW16/FLASH_CS: R1.2, U1.27 (FLASH_CS), U11.1 (~CS)
/ESP32-P4NRW16/FLASH_D: U1.33 (FLASH_D), U11.5 (DI(IO0))
/ESP32-P4NRW16/FLASH_HOLD: U1.31 (FLASH_HOLD), U11.7 (/HLD/RST(IO3))
/ESP32-P4NRW16/FLASH_Q: U1.28 (FLASH_Q), U11.2 (DO(IO1))
/ESP32-P4NRW16/FLASH_WP: U1.29 (FLASH_WP), U11.3 (/WP(IO2))
/ESP32-P4NRW16/GPIO2_MTCK: J1.9, U1.2 (GPIO2_MTCK)
/ESP32-P4NRW16/GPIO3_MTDI: J1.7, U1.3 (GPIO3_MTDI)
/ESP32-P4NRW16/GPIO4_MTMS: J1.5, U1.4 (GPIO4_MTMS)
/ESP32-P4NRW16/GPIO5_MTDO: J1.3, U1.5 (GPIO5_MTDO)
/ESP32-P4NRW16/GPIO13: J1.8, U1.14 (GPIO13)
/ESP32-P4NRW16/GPIO16: R19.1, U1.17 (GPIO16)
/ESP32-P4NRW16/GPIO17: DI2.2 (K2), FPC7.21, J13.1, R30.2, U1.18 (GPIO17)
/ESP32-P4NRW16/GPIO18: DI2.1 (K1), FPC7.20, J13.5, R31.2, U1.19 (GPIO18)
/ESP32-P4NRW16/GPIO19: FPC7.17, U1.20 (GPIO19)
/ESP32-P4NRW16/GPIO20_SPI_MOSI: RN17.4 (R4.1), U1.22 (GPIO20)
/ESP32-P4NRW16/GPIO21_SPI_MISO: RN17.3 (R3.1), U1.23 (GPIO21)
/ESP32-P4NRW16/GPIO22_SPI_CLK: RN17.2 (R2.1), U1.24 (GPIO22)
/ESP32-P4NRW16/GPIO23_SPI_CS: RN17.1 (R1.1), U1.25 (GPIO23)
/ESP32-P4NRW16/GPIO26_PARLIO: FPC2.2, RN3.1 (R1.1)
/ESP32-P4NRW16/GPIO26_PARLIO_R: RN3.8 (R1.2), U1.55 (GPIO26)
/ESP32-P4NRW16/GPIO27_PARLIO: FPC2.4, RN3.2 (R2.1)
/ESP32-P4NRW16/GPIO27_PARLIO_R: RN3.7 (R2.2), U1.56 (GPIO27)
/ESP32-P4NRW16/GPIO28_PARLIO: FPC2.6, RN3.3 (R3.1)
/ESP32-P4NRW16/GPIO28_PARLIO_R: RN3.6 (R3.2), U1.57 (GPIO28)
/ESP32-P4NRW16/GPIO29_PARLIO: FPC2.8, RN3.4 (R4.1)
/ESP32-P4NRW16/GPIO29_PARLIO_R: RN3.5 (R4.2), U1.58 (GPIO29)
/ESP32-P4NRW16/GPIO30_PARLIO: FPC2.10, RN4.1 (R1.1)
/ESP32-P4NRW16/GPIO30_PARLIO_R: RN4.8 (R1.2), U1.60 (GPIO30)
/ESP32-P4NRW16/GPIO31_PARLIO: FPC2.12, RN4.2 (R2.1)
/ESP32-P4NRW16/GPIO31_PARLIO_R: RN4.7 (R2.2), U1.61 (GPIO31)
/ESP32-P4NRW16/GPIO32_PARLIO: FPC2.14, RN4.3 (R3.1)
/ESP32-P4NRW16/GPIO32_PARLIO_R: RN4.6 (R3.2), U1.63 (GPIO32)
/ESP32-P4NRW16/GPIO33_PARLIO: FPC2.16, RN4.4 (R4.1)
/ESP32-P4NRW16/GPIO33_PARLIO_R: RN4.5 (R4.2), U1.64 (GPIO33)
/ESP32-P4NRW16/GPIO34_BOOTM: C41.2, R5.2, SW1.1, U1.65 (GPIO34_BOOTM)
/ESP32-P4NRW16/GPIO35_BOOTM: C77.2, R28.1, U1.66 (GPIO35_BOOTM), U9.3, U9.4
/ESP32-P4NRW16/GPIO36_BOOTM: R29.1, U1.68 (GPIO36_BOOTM)
/ESP32-P4NRW16/GPIO37_BOOTM_UART0_TXD: J13.2, U1.69 (GPIO37_BOOTM)
/ESP32-P4NRW16/GPIO38_BOOTM_UART0_RXD: J13.6, U1.70 (GPIO38_BOOTM)
/ESP32-P4NRW16/GPIO39_CDATA0_R: RN14.8 (R1.2), U1.80 (GPIO39)
/ESP32-P4NRW16/GPIO40_CDATA1_R: RN14.7 (R2.2), U1.81 (GPIO40)
/ESP32-P4NRW16/GPIO41_CDATA2_R: RN14.6 (R3.2), U1.82 (GPIO41)
/ESP32-P4NRW16/GPIO42_CDATA3_R: RN14.5 (R4.2), U1.83 (GPIO42)
/ESP32-P4NRW16/GPIO43_CCLK_R: RN5.1 (R1.1), U1.84 (GPIO43)
/ESP32-P4NRW16/GPIO44_CCMD_R: RN5.4 (R4.1), U1.86 (GPIO44)
/ESP32-P4NRW16/GPIO47_PARLIO: FPC2.18, RN6.1 (R1.1)
/ESP32-P4NRW16/GPIO47_PARLIO_R: RN6.8 (R1.2), U1.89 (GPIO47)
/ESP32-P4NRW16/GPIO48_PARLIO: FPC2.20, RN6.2 (R2.1)
/ESP32-P4NRW16/GPIO48_PARLIO_R: RN6.7 (R2.2), U1.90 (GPIO48)
/ESP32-P4NRW16/GPIO49_PARLIO: FPC2.22, RN6.3 (R3.1)
/ESP32-P4NRW16/GPIO49_PARLIO_R: RN6.6 (R3.2), U1.92 (GPIO49)
/ESP32-P4NRW16/GPIO51: FPC2.24, U1.94 (GPIO51)
/ESP32-P4NRW16/GPIO52: FPC2.26, U1.95 (GPIO52)
/ESP32-P4NRW16/GPIO53: FPC2.28, U1.97 (GPIO53)
/ESP32-P4NRW16/GPIO54: FPC2.30, U1.98 (GPIO54)
/ESP32-P4NRW16/P4_USB_HS_DN: U1.49 (DM), U4.3 (I/O2)
/ESP32-P4NRW16/P4_USB_HS_DP: U1.50 (DP), U4.1 (I/O1)
/ESP32-P4NRW16/SP+: R19.2, SP1.1
/ESP32-P4NRW16/SPI2_CK: RN2.6 (R3.2), U1.10 (GPIO9_SPI2_CK)
/ESP32-P4NRW16/SPI2_CS: RN2.8 (R1.2), U1.7 (GPIO7_SPI2_CS)
/ESP32-P4NRW16/SPI2_MISO: RN2.5 (R4.2), U1.11 (GPIO10_SPI2_MISO)
/ESP32-P4NRW16/SPI2_MOSI: RN2.7 (R2.2), U1.8 (GPIO8_SPI2_MOSI)
/ESP32-P4NRW16/USB1P1_N: R20.1, U2.3 (I/O2)
/ESP32-P4NRW16/USB1P1_P: R21.1, U2.1 (I/O1)
/ESP32-P4NRW16/USB1P1_R_N: R20.2, U1.52 (GPIO24_USB1P1_N0)
/ESP32-P4NRW16/USB1P1_R_P: R21.2, U1.53 (GPIO25_USB1P1_P0)
/ESP32-P4NRW16/XTAL_N: R11.1, U1.99 (XTAL_N)
/ESP32-P4NRW16/XTAL_P: R9.1, U1.100 (XTAL_P)
/Interfaces/SPI_CLK: FPC1.7, RN17.7 (R2.2)
/Interfaces/SPI_CS: FPC1.9, RN17.8 (R1.2)
/Interfaces/SPI_MISO: FPC1.4, RN17.6 (R3.2)
/Interfaces/SPI_MOSI: FPC1.2, RN17.5 (R4.2)
/Power_Management/DVDT_0: C15.2, R41.2
/Power_Management/DVDT_1: C16.2, EF1.1 (DVDT)
/Power_Management/DVDT_R: ID1.7 (DVDT), R41.1
/Power_Management/EN/UVLO_0: ID1.1 (EN/UVLO), R15.2, R24.1
/Power_Management/EN/UVLO_1: EF1.2 (EN/UVLO), R36.2, R38.1
/Power_Management/FB1: C2.1, R10.2, R43.1, SMPS2.3 (FB1)
/Power_Management/ILM: EF1.7 (ILM), R40.1
/Power_Management/L1: L3.1, U6.4 (L1)
/Power_Management/L2: L3.2, U6.2 (L2)
/Power_Management/OVLO: ID1.2 (OVLO), R24.2, R25.1
/Power_Management/PWR+: C13.2, D4.1 (A1), ID1.5 (IN), JST2.1 (PWR+), R15.1
/Power_Management/PWR_C+: C14.2, D2.1 (K), D3.1 (K), EF1.3 (IN), EF1.4 (IN__1), ID1.6 (OUT), R36.1, TP8.1 (1_1)
/Power_Management/SW1: L1.1, SMPS2.6 (SW1)
/Power_Management/SW2: L2.1, SMPS2.12 (SW2)
/Power_Management/VINA: C40.2, R46.2, U6.6 (EN), U6.7 (PS_SYNC), U6.8 (VINA)
/Power_Management/~FLT: EF1.6 (~FLT), R39.2
/USB/USB_D1+: J6.A6 (D+), J6.B6 (D+), U4.6 (I/O1)
/USB/USB_D1-: J6.A7 (D-), J6.B7 (D-), U4.4 (I/O2)
/USB/USB_D2+: J9.A6 (D+), J9.B6 (D+), U2.6 (I/O1)
/USB/USB_D2-: J9.A7 (D-), J9.B7 (D-), U2.4 (I/O2)
ESP_3V3: C2.2, C9.1, C17.1, C21.2, C22.2, C29.1, C32.1, C33.1, C34.1, C35.1, C36.2, C37.1, C50.1, C53.1, C54.1, C55.1, C57.1, C63.1, C64.1, C67.1, C68.1, C69.1, C73.1, C74.1, C75.1, C76.1, C89.1, C90.1, C91.1, C92.1, C93.1, C94.1, FB2.2, FPC7.22, IC1.1 (VDDA6), IC1.3 (VDDA7), IC1.6 (VDDA8), IC1.8 (VDDPST1), IC1.24 (VDDPST2), IC1.39 (VDDPST3), IC1.44 (VDDA3), IC1.45 (VDDA4), IC1.46 (VDDA5), IC2.14 (VDD), IC3.5 (VIO), J1.11, J2.1, L1.2, R5.1, R6.1, R7.1, R10.1, R16.1, R23.1, R26.1, R27.1, R28.2, R29.2, R39.1, R42.1, RN1.5, TP5.1 (1_1), TP10.1 (1_1), U1.9 (VDD_LP), U1.21 (VDD_IO_0), U1.51 (VDD_USBPHY), U1.62 (VDD_IO_4), U1.75 (VDDPST_LDO), U1.77 (VDD_DCDCC), U1.96 (VDD_IO_6), U1.101 (VDDA), U1.102 (VBAT), U14.5 (VCC), U15.5 (VCC)
ESP_FLASH: C8.1, C59.1, C65.1, C66.1, R1.1, U1.30 (VDD_FLASHIO), U1.71 (VDDO_FLASH), U11.8 (VCC)
ESP_LDO_VDDO_3: C10.1, C11.1, C12.1, C56.1, U1.41 (VDD_MIPI_DPHY), U1.73 (VDDO_3)
ESP_LDO_VDDO_4: C49.1, C51.1, C52.1, U1.74 (VDDO_4), U1.85 (VDD_IO_5)
ESP_LDO_VDDO_PSRAM: C58.1, C61.1, C62.1, U1.59 (VDD_PSRAM_0), U1.67 (VDD_PSRAM_1), U1.72 (VDDO_PSRAM)
ESP_VDD_HP: C23.2, C24.2, C25.2, C60.1, C70.1, C71.1, C72.1, L2.2, R44.1, TP6.1 (1_1), U1.26 (VDD_HP_0), U1.76 (VDD_HP_2), U1.91 (VDD_HP_3)
GND: C1.2, C3.2, C4.2, C5.2, C6.2, C7.2, C8.2, C9.2, C10.2, C11.2, C12.2, C13.1, C14.1, C15.1, C16.1, C17.2, C19.1, C20.1, C21.1, C22.1, C24.1, C25.1, C26.1, C27.1, C28.2, C29.2, C30.2, C32.2, C33.2, C34.2, C35.2, C36.1, C37.2, C38.2, C39.2, C40.1, C41.1, C42.1, C43.1, C44.1, C49.2, C50.2, C51.2, C52.2, C53.2, C54.2, C55.2, C56.2, C57.2, C58.2, C59.2, C60.2, C61.2, C62.2, C63.2, C64.2, C65.2, C66.2, C67.2, C68.2, C69.2, C70.2, C71.2, C72.2, C73.2, C74.2, C75.2, C76.2, C77.1, C83.2, C84.2, C85.2, C89.2, C90.2, C91.2, C92.2, C93.2, C94.2, C96.2, D4.2 (A2), DI2.3 (CC), DP1.1 (GND), DP1.3 (GND), DP1.5 (GND), EF1.8 (GND), EF1.9 (GND__1), FPC1.1, FPC1.3, FPC1.5, FPC1.6, FPC1.8, FPC1.10, FPC1.11 (MP1), FPC1.12 (MP2), FPC2.1, FPC2.3, FPC2.5, FPC2.7, FPC2.9, FPC2.11, FPC2.13, FPC2.15, FPC2.17, FPC2.19, FPC2.21, FPC2.23, FPC2.25, FPC2.27, FPC2.29, FPC2.SH1, FPC2.SH2, FPC7.1, FPC7.4, FPC7.7, FPC7.10, FPC7.13, FPC7.16, FPC7.19, FPC7.23, FPC7.24, H1.1 (1_1), H2.1 (1_1), H3.1 (1_1), H4.1 (1_1), IC1.2 (GND_1), IC1.36 (GPIO26_BOOT), IC1.43 (GND_2), IC1.47 (GND_3), IC1.49 (GND_4), IC2.7 (VSS), IC3.2 (GND), IC3.8 (STBY), ID1.4 (PGTH), ID1.8 (GND), ID1.9 (IMON), J1.2, J1.4, J1.6, J1.10, J1.12, J2.2, J2.3, J2.7, J2.9, J2.11, J2.13, J3.1 (GND), J3.2 (GND), J6.A1 (GND), J6.A12 (GND), J6.B1 (GND), J6.B12 (GND), J6.S1 (SHIELD), J9.A1 (GND), J9.A12 (GND), J9.B1 (GND), J9.B12 (GND), J9.S1 (SHIELD), J13.3, J13.4, JP1.1 (A), JST1.3 (GND), JST2.2 (PWR-), R8.1, R12.2, R13.2, R17.2, R18.2, R25.2, R37.2, R38.2, R40.2, R43.2, R45.2, RN5.2 (R2.1), RN5.3 (R3.1), RN5.6 (R3.2), RN5.7 (R2.2), RN6.4 (R4.1), RN6.5 (R4.2), SMPS2.2 (GND_1), SMPS2.9 (GND_2), SP1.2, SW1.2, U1.105 (GND), U2.2 (GND), U4.2 (GND), U5.4 (GND), U6.3 (PGND), U6.9 (GND), U6.11 (PAD), U9.1, U9.2, U11.4 (GND), U12.1, U12.2, U13.1, U13.2, U14.3 (GND), U15.3 (GND), Y1.2, Y1.4, Y2.2, Y2.4, Y3.2, Y3.4
unnamed: C83.1, R4.2, Y3.1
unnamed: C84.1, R9.2, Y2.1
unnamed: C85.1, R11.2, Y2.3
unnamed: C96.1, IC1.4 (XTAL_N), Y3.3
unnamed: IC1.5 (XTAL_P), R4.1
unnamed: J6.A5 (CC1), R12.1
unnamed: J6.B5 (CC2), R13.1
unnamed: J9.A5 (CC1), R17.1
unnamed: J9.B5 (CC2), R18.1
PWR_D+: C26.2, C27.2, C42.2, EF1.5 (OUT), R46.1, SMPS2.5 (MODE_/SYNC), SMPS2.7 (VIN1), SMPS2.8 (EN1), SMPS2.11 (VIN2), SMPS2.14 (COMP_/FSET), TP7.1 (1_1), U6.5 (VIN)
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

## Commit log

2026-05-09 Updated notes
    [ESP32P4C5_Board.kicad_pcb, Notes.kicad_sch, Power_Management.kicad_sch]
2026-05-13 SMA Update
    [ESP32-C5HR8.kicad_sch, ESP32-P4NRW16.kicad_sch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]
2026-05-24 QSPI Memory Bus
    [CAN-FD_BUS.kicad_sch, ESP32-C5HR8.kicad_sch, ESP32-P4NRW16.kicad_sch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]
2026-06-03 Interface Update
    [CAN-FD_BUS.kicad_sch, ESP32-C5HR8.kicad_sch, ESP32-P4NRW16.kicad_sch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]
2026-06-11 Small trace layout fixes
    [CAN-FD_BUS.kicad_sch, ESP32-C5HR8.kicad_sch, ESP32-P4NRW16.kicad_sch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]
2026-06-16 Power rail update
    [ESP32-C5HR8.kicad_sch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]
2026-06-19 5V SMPS
    [ESP32P4C5_Board.kicad_pcb, Power_Management.kicad_sch]
2026-07-04 Readme updated
    [ESP32-P4NRW16.kicad_sch, ESP32P4C5_Board.kicad_pcb, ESP32P4C5_Board.kicad_sch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]
2026-07-04 PCB Layout PDF
    [ESP32-P4NRW16.kicad_sch, ESP32P4C5_Board.kicad_pcb, ESP32P4C5_Board.kicad_sch]
2026-07-05 Block Diagram
    [ESP32P4C5_Board.kicad_pcb]
